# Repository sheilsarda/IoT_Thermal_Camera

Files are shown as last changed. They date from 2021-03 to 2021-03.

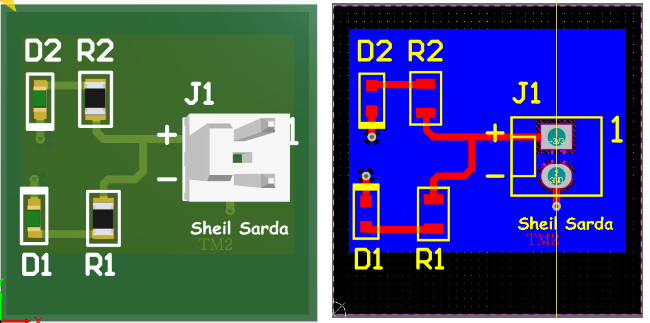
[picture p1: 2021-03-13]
Lab4/ESE516_SheilSarda_A4.png

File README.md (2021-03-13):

# Radiance-T 

IOT Device for Non Contact Temperature Measurement and Thermal Image Mapping 

## Inspiration
"**Industry 4.0** fosters what has been called a "smart factory". Within modular structured smart factories, cyber-physical systems monitor physical processes and make decentralized decisions. Industrial Internet of Things (IIoT) systems enable the connectivity of numerous heterogeneous devices and other assets into one system to derive more intelligent actions from data. The application of the IIoT in industrial production systems is known as Industry 4.0".(_[Wikipedia]_ [ABB_D]_)

Industrial automation companies including ABB, Bosch, BMW and Audi envision that in these smart factories of the future people will control the operations and make decisions based on measurement data from the factory's equipment, as well as information regarding the availability of raw materials and the price of energy. This will improve productivity, in more environmentally friendly manner and reduce costs. (_[ABB]_).

Our product, **Radiance-T** will give manufacturers the ability to transition personnel to more value-added activities, providing the foundation to extend and expand product and service offerings. As they look to expand globally, our automated temperature and thermal image monitoring solution will maintain process consistency across locations. The information will be delivered to experts who are far away from the facility itself, for example in applications for the oil and gas industry or for offshore wind power plants. The product can pre-emptively detect and analyze faults and send reports to operation and production planning systems.

## What it does
Our device provides clients with the ability to remotely access data from **Radiance**'s on-board thermographic camera and thermopile sensors to enforce quality control standards of temperature-sensitive goods such as perishables or heat-sensitive chemicals during processing or manufacturing. It enables clients to monitor and perform operations effectively on assembly and manufacturing lines. It provides the visual sight on location where human inspection or visual camera monitoring are difficult.

**Radiance**'s sensors are mounted on a 180-degree swivel platform powered by a remotely controlled servo motor, allowing the client to get temperature readings with a 235-degree field of view. All the logged data is easy accessible to clients via our cloud dashboard.

Clients can also update **Radiance**'s firmware to take advantage of the latest features using the Over The Air Firmware Update capabilities accessible through our cloud application interface/dashboard. 
Increasing automation improves the quality of the entire value chain. The person can use information to program and control operations and make decisions to optimize the quality, safety, efficiency and environmental aspects of production. 

**Application Features** </br>

## How we built it
1. Product design phase with feature and sensor selection.
2. Designing electrical schematics using Altium Designer to enable PCB design.
3. Designing PCB, routing components, satisfying manufacturers Design Rule Checks.
5. Exporting PCB design, submitting it to manufacturer and resolving any last-minute issues.
4. Developing firmware for the PCB, including developing a CLI, Bootloader, and OTAFU functionality using the Atmel Studio IDE and ASF libraries for the SAMD21 MCU.
6. Connecting the hardware to Node-Red using the MQTT broker.
7. Designing UI Interface for **Radiance** using Node-Red IDE with simulation functionality.
8. Perform board bring-up on our manufactured PCBs, and integrate sensors using I2C, Serial and ADC interfaces.

## Challenges we ran into
**Firmware Integration.** Following the checkpoint structure of the course, we developed all the core firmware functionality such as CLI, boot loader, OTAFU and each sensor's interface in independent projects. In the last few weeks of the course when we tried to merge all the software projects to create a singular 2000+ line project, we ran into a lot of conflicts. Examples were using different timers, sensor modules using the same SERCOM pins, or condensing or trying to compress a polling-based while(true) loop using interrupt driven programming. 

**PCB Design.** Our primary challenge in the second stage of our project was narrowing down the functionality and complexity of our board to fit under the $30 / board budget. Significant challenges we faced when tasked with designing the schematics and the board for our PCB, component selection based on size, availability and cost was major challenge. Moreover, complying with PCB manufacture's requirement was most important thing in this phase. 

**PCB Bring-up.**  Testing signal connectivity and voltage levels and making sure power blocks works as we designed them for.

**Sensor Integration** - Interfacing two different I2C sensors on the same I2C line with master processor and calibration of complex temperature sensor on the board.   

**Product Management**- Cost and timeline were major challenges in the development life cycle 

## Accomplishments that we're proud of
+  Build a working prototype for Radiance -T which can be tested with conditions
+  Designed a dashboard and analytics engine which works on cloud computing 
+  IOT practicum and hands on experience on industry standard  product development  
+  Successfully completing a IOT Edge Computing course at Penn

## What we learned
1. Building an IOT device from the ground up. 
2. The building blocks and technical requirements for developing a complete and generic IOT product
3. Circuit Design, PCB design and Firmware development using industry standard software and tools. 
4. Sensor Integration, Cloud connections, Wireless Communication and Power Management techniques
5. Processor, component and material selection and development timeline 
6. IOT design thinking, different phases and challenges in developing a product 

## What's next for Radiance
We are envisioning of building a minimal viable product and testing it on sight with more powerful sensors and analytics engine. We are planning to create a network of Radiance devices and automate the processes for smart factory. While creating Radiance's MVP, we are expanding the application of device in consumer and retail supply chain sector.  Data measurement and predictability will increase the operational reliability, uniformity, cost-effectiveness and safety all while making it easier to control remote locations. 

[Wikipedia]: https://en.wikipedia.org/wiki/Industry_4.0
[ABB]: https://new.abb.com/docs/default-source/technology/a-new-age-of-industrial-production---iotsp.pdf
[ABB_D]: https://new.abb.com/news/detail/11242/digital-twin-a-key-software-component-of-industry-40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

## Course Wrap-up (from Prof. Garcia's email)

Hello Everyone:

Thank you very much for your time and energy in this semester's class. I wanted to send this email as a wrap up of the class, to indicate some tips and next steps that I hope can prove useful. As an additional note, I have attached the Microchip Crypto Primer slides that Dan presented to the class.

### What comes after Altium - Alternatives

In the class we learned about PCB Design using Altium Studio which fortunately Penn has licenses for. There are free alternatives in case you want to continue developing PCBs but do not have access to Altium. They are:

1. [Circuit Maker](https://circuitmaker.com/). This is the online-based free version of Altium. will have most of the utility seen in class.  It is cloud based, which means all the projects will live on the cloud. I have used it and I consider it pretty good.
1. [KiCad](http://kicad-pcb.org/). Open source software for PCB development. Very popular alternative to Altium, and Free! It is also cross platform.
1. [Autodesk Eagle](https://www.autodesk.com/products/eagle/overview). I have not used it since the days it was free. Now it is $15 a month.

### PCB Fabrication
This class used PCB:NG for mixed results. I wanted to share some of my favorite PCB manufacturers with you to keep in mind if you want to do future PCB work.

1. [PCBWAY](https://www.pcbway.com/). Very good PCB fab house, based in China. You can quote the cost on the PCB and assembly online, and their process is very good. You can tell them (for assembly) to buy the components themselves, or send it to them directly from Digikey. I fully recommend them!
1. [Sierra Circuits](https://www.protoexpress.com/). Very good PCB fab house in the States (California). Really good turnaround - I would consider them if you are doing something for work or school - they are not in the price range for hobbyists! Their main advantage lies in that they do a very thorough analisys of your design, and they are very good at "catching" manufacturability issues and letting you know so they can be fixed.

### Interesting Microcontroller Recommendations

There are multiple interesting microcontrollers out there, each with their own advantages. i wanted to share some in case you would like to know more about them. The following options have very inexpensive dev kits you can buy on Amazon or Digikey.

1. ST: I really like ST and use them extensively. They have a supporting software, called CubeMX, which really helps with the phase of HW and FW design (very similar to Atmel Start). Give them a try!  https://www.st.com/content/st_com/en/support/learning/stm32-education.html
1. Rigado: If you need Bluetooth, I heavily recommend a micro from Nordic! Nordic make really good MCUs with built in Bluetooth, but they are very small and sometimes their size alone can drive the cost of the PCB manufacturing (smaller vias and traces equals a more expensive board!). This is sometimes dealt with with the use of modules. Rigado makes modules based on the Nordic chips that take care of complicated electronics needed to run the Nordic chip, and give you a nice module (A la SAMW25). They use a really good (free) development studio called Segger Embedded Studio (free for using the Nordic chips). Give them a try!  https://www.rigado.com/products/wireless-modules/

### Connectors

There exists a ton of connectors, and sometimes you may have seen a connector but have no idea what the name is to find them online! It happens to me a lot.

For this, I recommend the Connector page of Digikey (accesible from the front splash page - on the left, click on "connectors"). Or see this link: https://www.digikey.com/en/resources/connectors/index

You can then go through the connector selection with representative images of the connectors on each category.

### How useful is to know how to make PCBs? And how useful is to do personal projects as an Engineer?

I hope this class gave you the resources you need to bring any electrical project to manufacturing, be it a class project, an academia project, or an industry project.

As a finishing point I wanted to explain how important it is to do personal projects that you can showcase as a portafolio. Projects can be a great way to find new laboral opportunities and to showcase your skills and stand out.

As an example, I wanted to share the work of a friend and colleague. His name is Samson March, and he had been working as a pet project on making his own smart watch. I can attest he worked on it for a really long time. He recently published his project as a Open Source Project, and the project gained so much traction online that he started receiving job opportunities from very interesting companies. You can see the project [here](https://www.theverge.com/circuitbreaker/2019/5/5/18528008/smartwatch-build-your-own-diy-wearable).

I mention this example as a way to motivate you to do your own projects, which I hope this class helped on how to do. Also, on the importance of documentation of said projects! I would recommend, as you do your future school projects or personal projects, to document them AND to take nice pictures! I recommend lightboxes available on Amazon if you want to take nice pictures (Price around 10-50 dollars).

### Keep in Touch

If you want to keep in touch with me, my email is:

- `egarcia@bresslergroup.com`
- `edgarc@seas.upenn.edu`
- LinkedIn: `www.linkedin.com/in/EduardoEEGarcia`

Thank you everyone again for a great semester

Thanks!

-Eduardo

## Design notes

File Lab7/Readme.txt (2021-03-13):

README:
In order to check OTAFU via our dashboard, you can find the correct version numbers and CRC32 values by visiting
https://www.seas.upenn.edu/~sheils/metadata.txt

Line 1 of the metadata file is the version number, line 2 is the CRC32.
You will need to input these values to the Security Tab of our dashboard in order to successfuly update the Application Code.

The ApplicationCode.bin file being downloaded by OTAFU is hosted at 
https://www.seas.upenn.edu/~sheils/ApplicationCode.bin

You can find our dashboard at
https://radiancet.mybluemix.net/ui/#!/0

Since we did not make any modifications to our bootloader from A6, we did not need to add the bootloader project to our Atmel Studio solution for A7. The packaged code submitted in this directory is our application code for A7 only.

Our A6 Bootloader code can be found in the A6 folder in our project directory.

For the purposes of adding modules that we will be using in our final project, we added the Sercom I2C slave and master drivers, in addition to the Sercom SPI serial driver.

For testing purposes, we have also attateched the pre-OTAFU bin files and CRC files, which our bootloader expects to be loaded on the SD Card prior to boot. The post-OTAFU equivalents are hosted on the Penn server.

End to end OTAFU Demo: https://www.youtube.com/watch?v=R9AgcVQNr38

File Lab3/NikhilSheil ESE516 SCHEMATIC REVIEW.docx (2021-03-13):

# ESE516 SCHEMATIC REVIEW (A3)

Review Team | NikhilSheil
Teammember A | Nikhil Jamdade
Teammember B | Sheil Sarda
Reviewer | Eduardo Garcia
Date | Feb 24 2019
Project File | ESE516_ExampleBaseProject_V2.PrjPcb (Feb 22, 2019)

Main Schematic

• Good idea on connecting the BQ Enable and SYSOFF to the MCU Pins. However, for safety I recommend adding pulldowns or pullups depending on the default setting you want. I recommend putting a 10k pulldown on each of lines (BQ_SYSOFF, BQ_EN1, BQ_EN2). I also recommend removing the inline jumpers – they are now needed in this case.

- VUSB are not connected – was your intention to use an external supply just in case? In general, use Power ports for power nets.

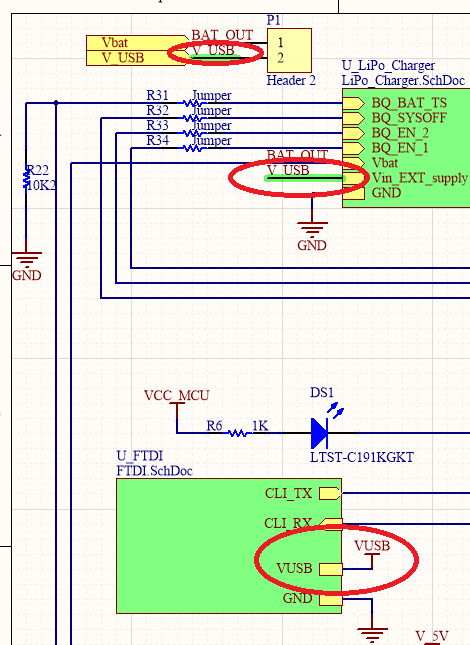
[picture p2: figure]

- For the battery connector, please add its own connector with VBAT and GND.
- Critical: The buzzer needs a square wave, make sure the pin you chose can do a PWM output. Also, you need to add a BJT to handle the current – see the datasheet. The MCU cannot provide the current needed directly from the pins.

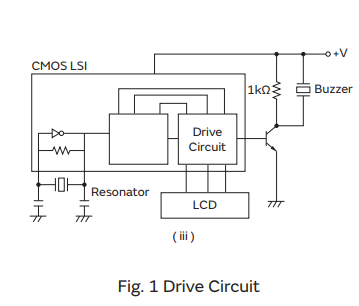
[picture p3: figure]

- Resistor R21 is not doing anything

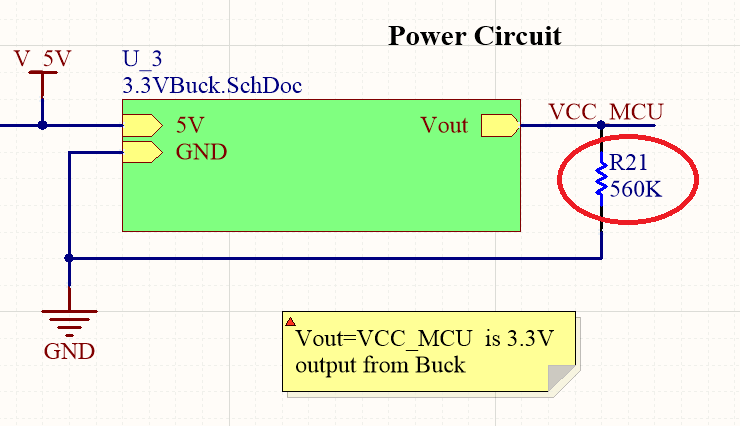
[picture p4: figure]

- Please add ERC to pins not used.
- Add testpoints for I2C lines and INT lines as well as servo PWM and feedback.

LiPo Fuel Gauge Schematic

- Please add a ground port to make the schematic clearer.
- Please change the designator of the device from Fuel Gauge to U? where the ? is an unique number in your design.
- This IC has no associated footprint. Please make and add the respective footprint.
- Please add the MPN. I cannot review without it.
- Critical: Device is wrong! Pin numbers are incorrect. Please double check with datasheet and update the device to have the correct pinout.
- Critical: The schematic is wrong! Please follow section 10.2 of the datasheet: http://www.ti.com/lit/ds/symlink/bq27441-g1.pdf

5V BOOST

- Critical - TPS61230DRCR needs a feedback resistor divider – please see the datasheet. HOWEVER, if you meant to use the TPS61232DRC, which is the fixed 5V output, then you can leave FB connected, but you have to change the component to be TPS61232DRC.

3V3 BUCK

- Component has some issues:
  - Critical: Component is wrong! Pins are incorrect. Please redo part and check datasheet Section 5: http://www.ti.com/lit/ds/symlink/tlv62568a.pdf
  - Critical: Feedback resistors are missing. Please check datasheet Section 5: http://www.ti.com/lit/ds/symlink/tlv62568a.pdf

IR Thermometer

- Component has no associated footprint

• Please change the designator of the device to U? where the ? is an unique number in your design.

- Add MPN to device. I am assuming it is the MLX90614ESF-BAA-000-TU

Servo Motor Schematic

- Component has no footprint. Please associate a footprint.

Thermal Camera Schematic

- Component is missing pin names and footprint. Fortunately the AMG8833 component is available on Altium Vault – please consider using that one, or fix your existing component.
- Please check the schematic with https://learn.adafruit.com/assets/43011 . R36 is doing nothing – if you want to have the option of selecting high or low, put a jumper between the AD_Select pin and ground.

MCU Schematic

pin checkout

SERCOM 1 is for SPI for WINC

SERCOM 4 is for UART CLI

SERCOM 3 for IR I2C – PA17 SCL, PA22 SDA

SERCOM 0 for Thermal and fuel gauge – PA08 SDA, PA09 SCL

ADC A0 PA02 for analog input

PA24: TC5/WO[0] OR TCC1/ WO[2]

- Critical: PA09 is connected as if it were SDA but Atmel Start tells me it is SCL. SAME FOR PA08. Please double check and fix!
- Critical: The analog of the SAMD21 must be from 0V to VCCA/2 (which is 1.65V). You will need to use a voltage divider to scale the ADC input from the servo. Also, the net label should read SERVO_ADC, not SERVO_DAC
- I recommend adding a button and an extra LED for debugging purposes or for system on/off.
- Please connect pin 10 to GND.

General Comments

Please review ALL the components that were made by hand. They have missing footprints and the symbols are wrong. Refer to the tutorial we did in class for steps on how to do this.

Add an external connector for the battery only (positive and negative terminal).

I recommend to implement the fixes and pair review the schematic.

Grade:

Component: -40 points: There are multiple component issues that if they made it to manufacturing would make the board not work. Please pair review the components you make with the datasheet, as it is easy to miss mistakes. Also, make sure footprints are associated with component.

Schematic Errors: -25 points: There are some errors that could have been caught if you double check the layout with the datasheet (which is something I recommend you to always do). It is easy to make mistakes while wiring schematics.

Grade: 235/300

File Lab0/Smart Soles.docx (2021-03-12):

# Smart Soles

# Navigation for the Differently Abled

I wish to build an IoT connected insoles to assist the differently-abled population (sight or sound impaired, for instance) safely navigate to their destination using directions provided in the form of haptic feedback from the shoes.

My idea of this device would consist of the following:

- 4 x Vibrating motor (or any low current motor) – two in each shoe
- 2 x Motor Drivers – each can drive up to 3 motors
- Wi-Fi chip to fetch instructions from a server – these instructions will trigger the motors when user needs to change their trajectory
- GNSS / GPS chip to get position of the user – this is a necessary input in determining when to activate the motors

Considerations: If GPS turns out to be too expensive, can be figure out a lower cost alternative to localize the user using Wi-Fi perhaps? The tradeoff would be cost vs. accuracy.

Simple System Diagram

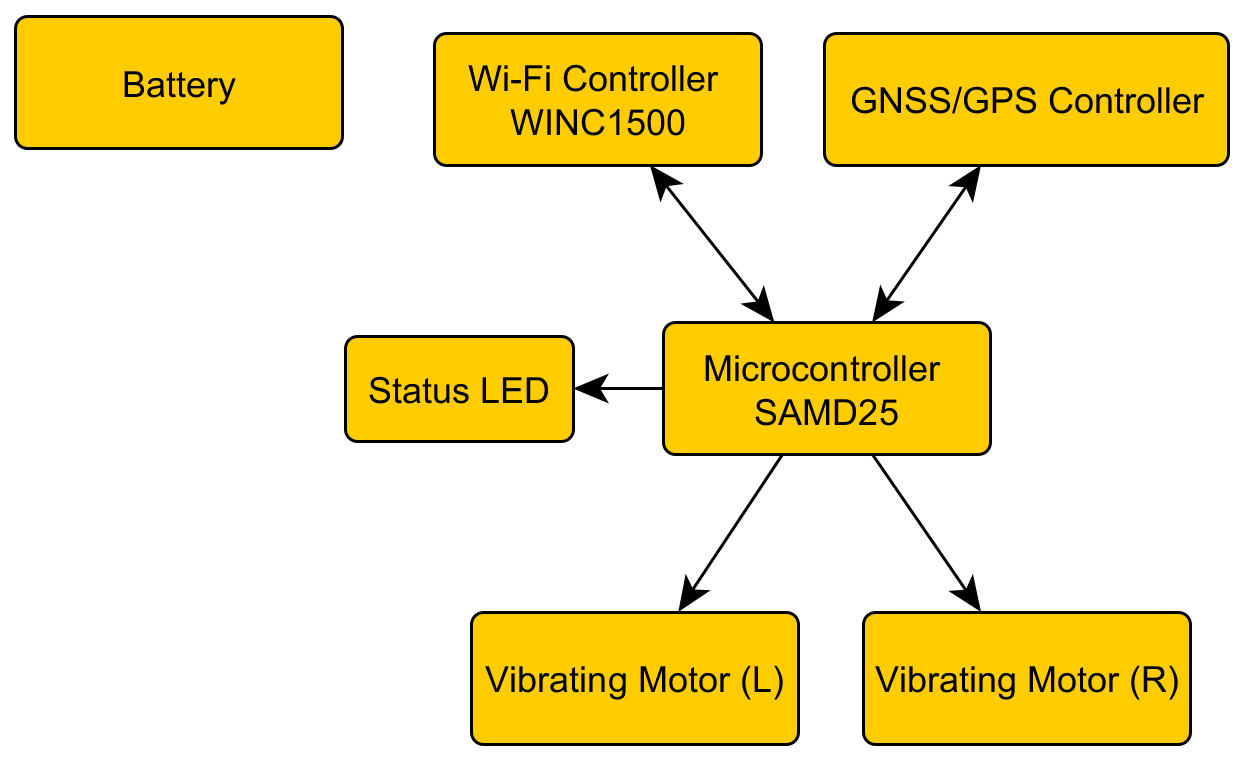
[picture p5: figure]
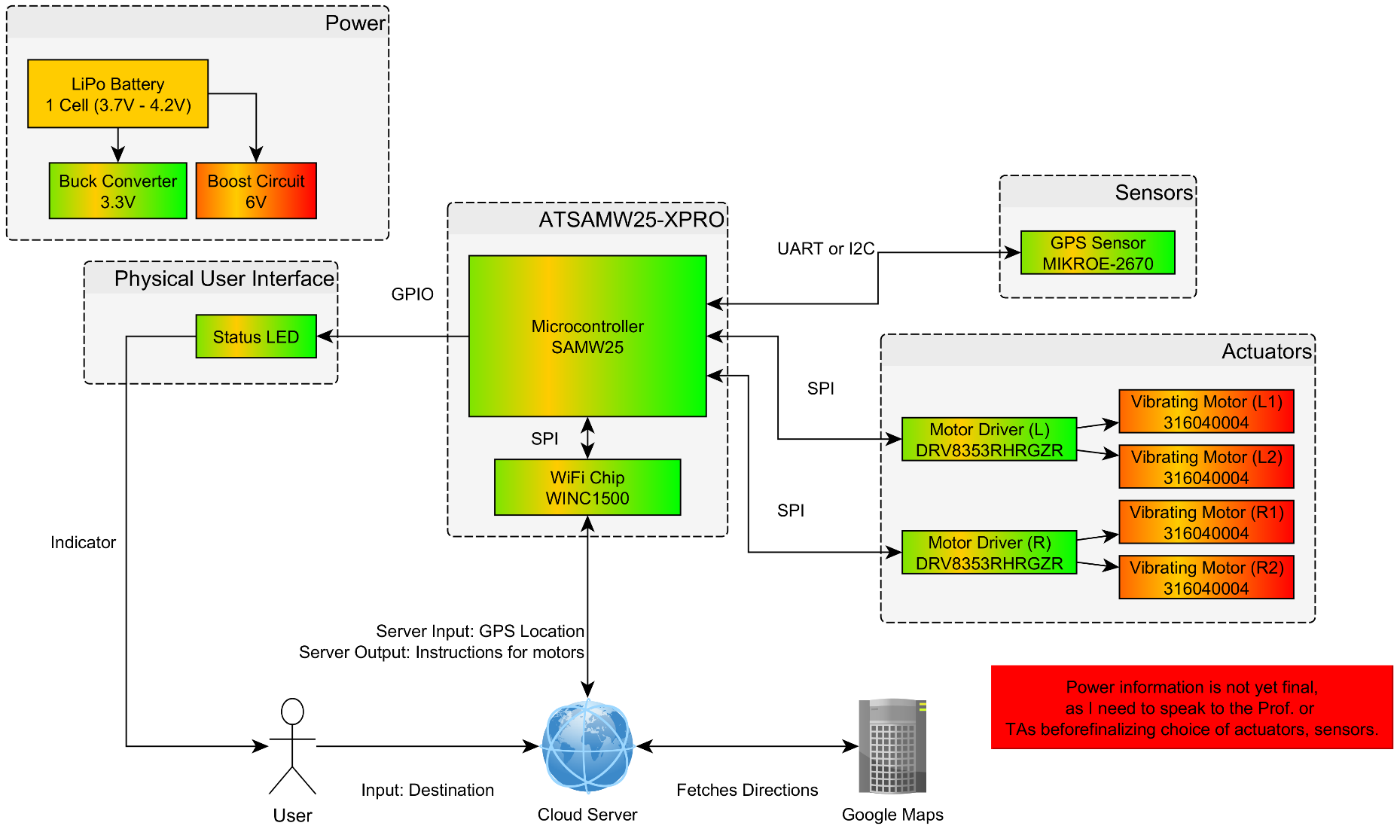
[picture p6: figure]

Detailed System Diagram

4.) Detailed System Diagram [50/50]

COMMENTS:

1.) Good description of the problem and good analysis of the technical challenges. Indeed! Location of a person on a building is a very hard problem - GPS can have issues inside buildings and usually has a tolerance that is ok to drive cars with, but it is too big for people walking inside buildings. There are some radios that try to do this location, but it is a hard problem. I worry that the product, as is ideally thought of, might be too hard to implement for this class. Let's talk after class this monday!

3.) The motor drivers are SPI drivers for thee phase BLCD motors. That is some serious motor controller! The vibrating motors you selected do not need this very complicated motor driver. For these motors, you can use either a simple BJT (turn on/off) or even more interesting, a haptic driver. Haptic driver are specialized drivers that allow you to do cool stuff with haptics. Check for example which is a better fir for your product.

https://www.adafruit.com/product/2305

Sheil Sarda ESE516 Project A0 Prof. Garcia

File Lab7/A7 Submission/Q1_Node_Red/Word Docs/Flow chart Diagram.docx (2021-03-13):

Radiance T : Flow Diagram from Device to MQTT to Cloud

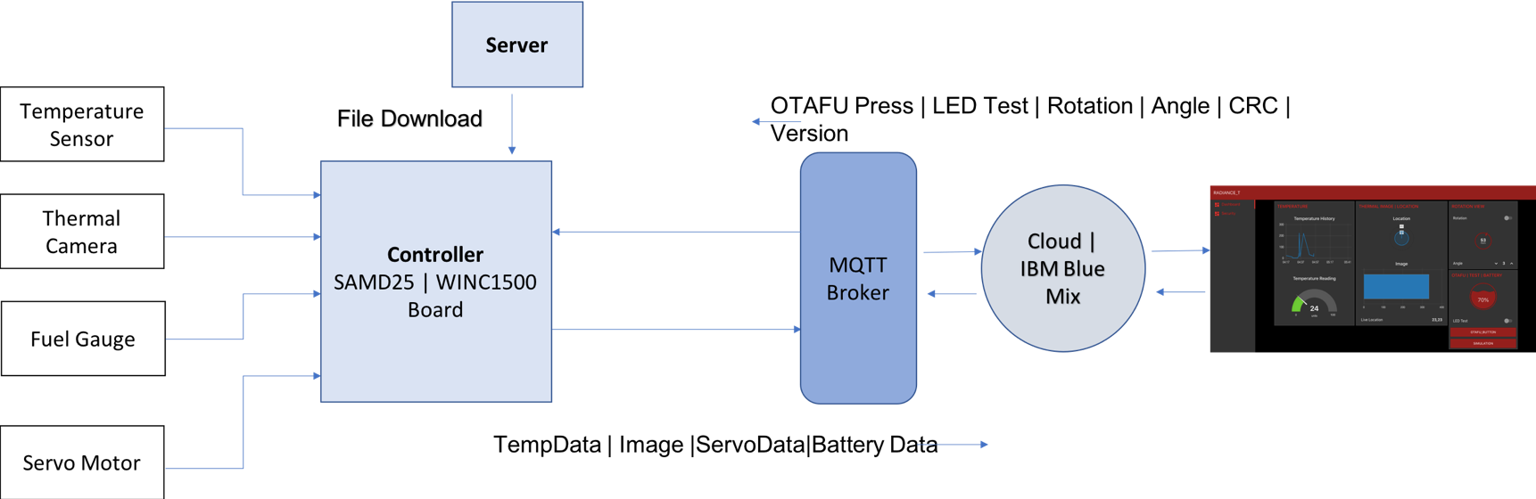
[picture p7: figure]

Message Transmission

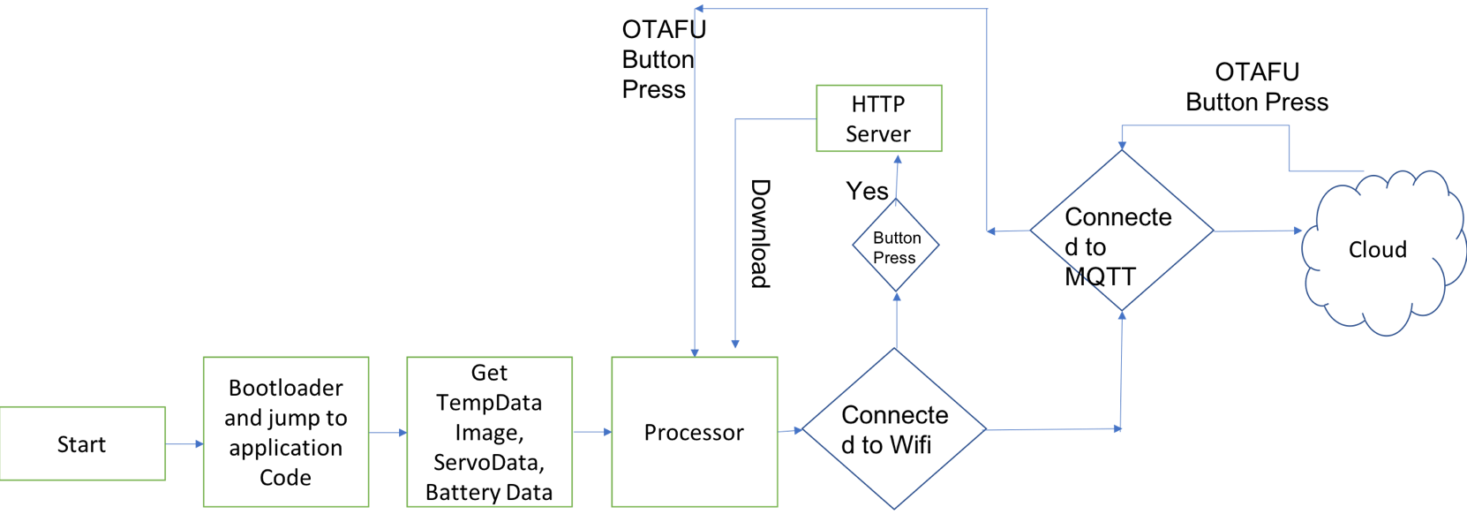
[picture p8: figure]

OTAFU Operation

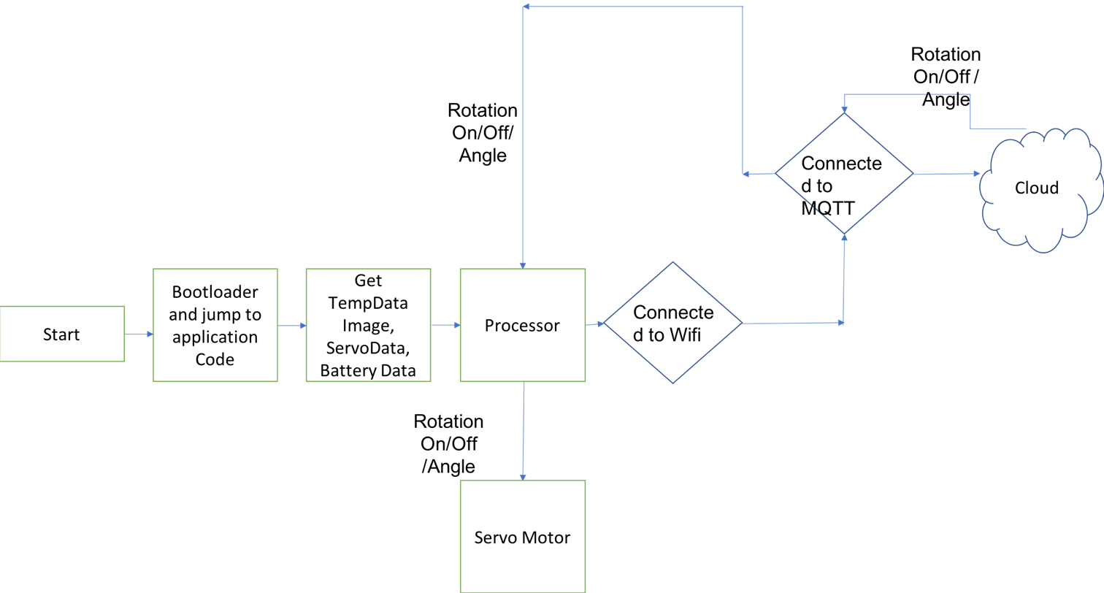
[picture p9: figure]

Servo Operation

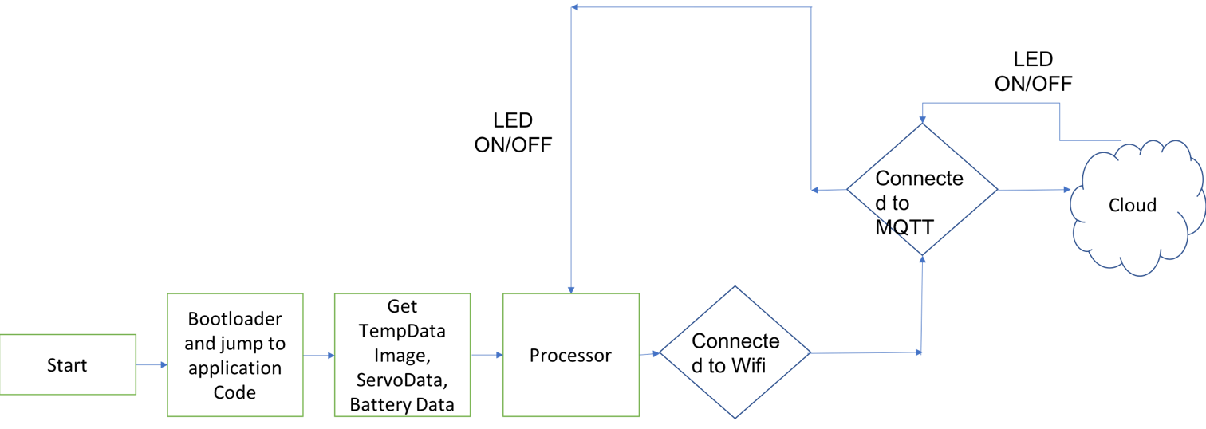
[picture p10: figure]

LED

Operation

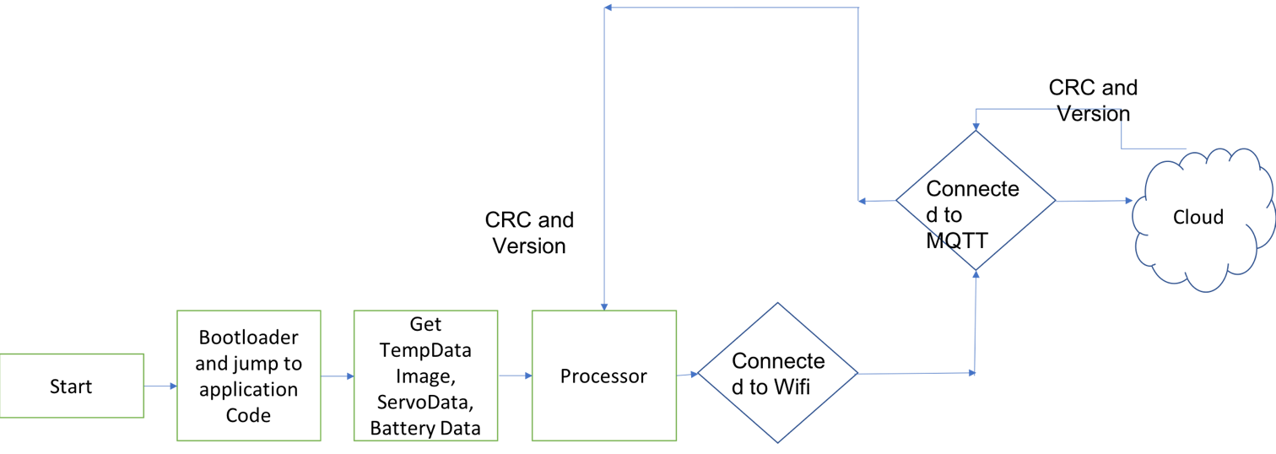
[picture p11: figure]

MetaData Trasfer

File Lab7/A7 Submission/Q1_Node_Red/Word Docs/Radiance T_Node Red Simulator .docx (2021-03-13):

Link to Node Red Radiance-T Dashboard

https://radiancet.mybluemix.net/ui/#!/0

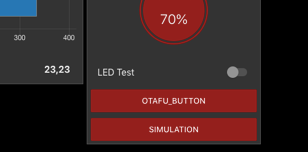
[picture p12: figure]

Device Simulator Node Red Diagram

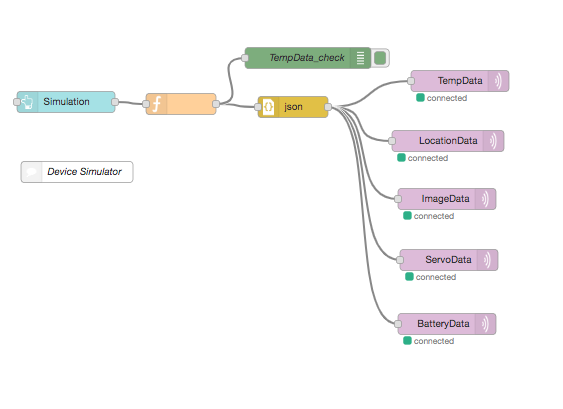
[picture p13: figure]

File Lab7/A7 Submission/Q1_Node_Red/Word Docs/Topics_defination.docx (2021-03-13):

ESE 516: Assignment A7

Creating the Node-Red dashboard for Radiance-T project

- Messages from Device ---- MQTT---- IBM Bluemix

Topic 1 : LocationData

Type : Number

JSON Structure:

var long1;

var lat1;

msg = {

payload: JSON.stringify(

{

d:{

"loc" :

{

"long" : long

"lat" : la1t },

}

} )

};

return msg;

Information – Sends the location coordinates or device id to display on the

Board. The graph on dashboard shows the location map.

Topic 2 : TempData

Type : Number

JSON Structure

Var temp1

msg = {

payload: JSON.stringify(

{

d:{

“temp” :temp1

}, } } )};

return msg;

Information – Sends the temperature data from IR temperature sensor on the device to

display and analyze temperature on cloud. The graph on dashboard shows the temperature history over time.

Topic 3 : ImageData

Type : Number Array

JSON Structure

Var image1=[1,2,3,4,5,6,7,8]

msg = {

payload: JSON.stringify(

{

d: {

“img” :{one: image1[0],two:image1[1], three:image1[3], four:image1[4]

}, } } )};

return msg;

Information – Sends the raw thermal image data group of bits/pixel from thermal camera on the device to display and analyze it on cloud.

Topic 4 : ServoData

Type : Number

JSON Structure

Var servo1

msg = {

payload: JSON.stringify(

{

d: {

“servo”:servo1

}, } } )};

return msg;

Information – Sends the stepper motor feedback/angle from device location to cloud. It is used to check the direction on sensor on device. It also gives rotation and movement of motor.

Topic 5 : BatteryData

Type : Number

JSON Structure

Var batt1

msg = {

payload: JSON.stringify(

{

d: {

“batt”:batt1

}, } } )};

return msg;

Information – Sends the reading of batter power from fuel gauge on device to cloud. It is used to show the amount of power left.

- Messages from IBM Bluemix------- MQTT------ Device

Topic 1: RotationData (ANGLE_TOPIC)

Type : Number

JSON Structure

int data

msg = {

payload: JSON.stringify(

{

d: {

data:data

}, } } )};

return msg;

Information – Sends the specific angle from cloud to rotate the motor on device side

Information – Sends the specific angle from cloud to rotate the motor on device side

Topic 2: StopData (STOP TOPIC)

Type : Boolean

JSON Structure

boolean data

msg = {

payload: JSON.stringify(

{

d: {

“datat”:data

}, } } )};

return msg;

Information – Sets continuous rotation of motor on or off- Rotation enable or disable

Topic 4: LedData (LED_TOPIC)

Type : Boolean

JSON Structure

boolean data

msg = {

payload: JSON.stringify(

{

d: {

“data”:data

}, } } )};

return msg;

Information – Sends signal from cloud to device to test the led on device

Topic 5: FW_Data (FW_TOPIC)

Type : Boolean

JSON Structure

Boolean data

msg = {

payload: JSON.stringify(

{

d: {

“data”:data

}, } } )};

return msg;

Information – Triggers OTAFU from cloud on device to download new firmware from server.

Topic 6: CRCData (CRC_TOPIC)

Type : String

JSON Structure

Char * data

msg = {

payload: JSON.stringify(

{

d: {

“data”:data

}, } } )};

return msg;

Information – Sends CRC string for OTAFU operation to write on SD card before download and update

Topic 6: VerData (VER_TOPIC)

Type : number

JSON Structure

Int * data

msg = {

payload: JSON.stringify(

{

d: {

“data”:data

}, } } )};

return msg;

Information – Sends version number for OTAFU operation to write on SD card before download and update

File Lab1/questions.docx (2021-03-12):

1.) What does “InitializeSerialConsole()” do? In said function, what is “cbufRx” and “cbufTx”?

It initializes the circular buffers handlers cbufRx, cbufTx as 8-bit integer buffers that use the underlying arrays rxCharacterBuffer and txCharacterBuffer while using 2 pointers to access different parts of the array. These circular buffers can hold at most 256 elements each.

2.) How are “cbufRx” and “cbufTx” initialized? Where is the library that defines them (please tell the *C file they come from).

They are initialized in the InitializeSerialConsole function inside SerialConsole.c

The function used to initialize them is called circular_buf_init, which is located in circular_buffer.c

In the initialization, we malloc and return a pointer to the space for the circular_buf_t struct, which contains the local variables necessary to implement the interface of the circular buffer using an underlying char array.

3.) Where are the character arrays where the RX and TX characters are being stored on at the end?

SerialConsole.c contains rxCharacterBuffer and txCharacterBuffer, which is where the RX and TX characters are being stored via the Circular Buffer interface

4.) Please draw a diagram that explain the program flow for UART reception – starting at the user typing a character and ending on how that characters ends up in the circular buffer “cbufRx”. Please make reference to specific functions in the starter code.

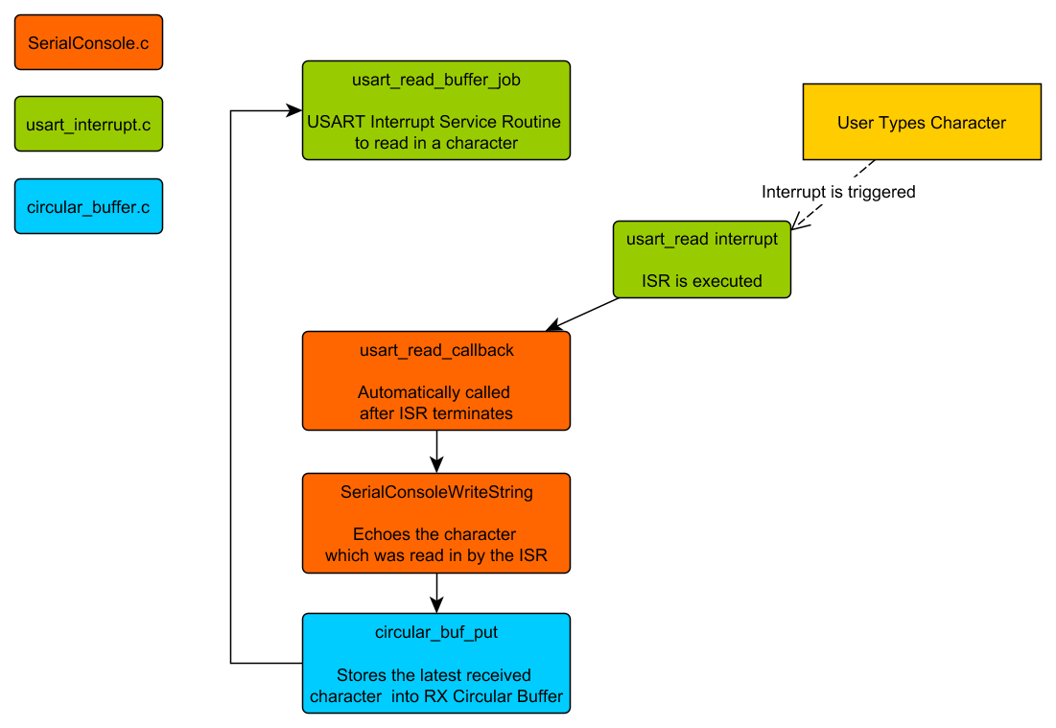
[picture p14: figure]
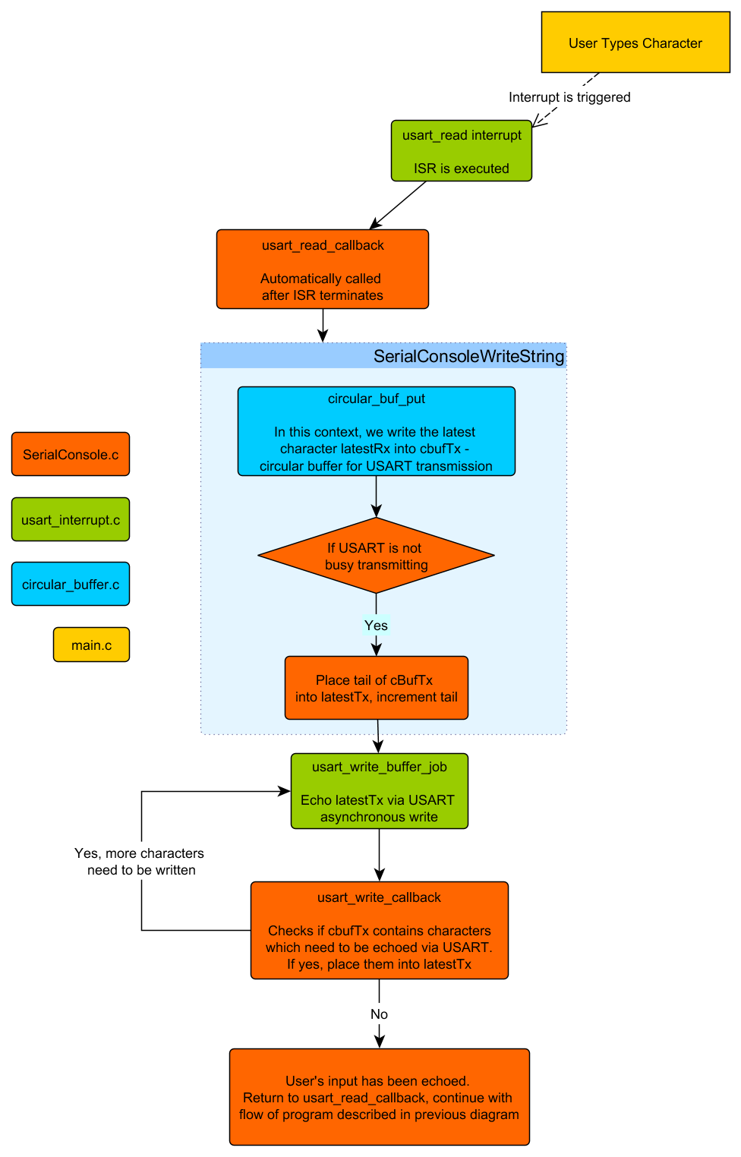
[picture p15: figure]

5.) Please draw a diagram that explain the program flow for the UART transmission – Starting from a string added by the program to the circular buffer “cbufTx” and ending on characters being shown on the screen of a PC (On Teraterm, for example). Please make reference to specific functions in the starter code.

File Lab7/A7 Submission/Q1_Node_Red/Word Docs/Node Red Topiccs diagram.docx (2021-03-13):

Link to Node Red Radiance-T Dashboard

https://radiancet.mybluemix.net/ui/#!/0

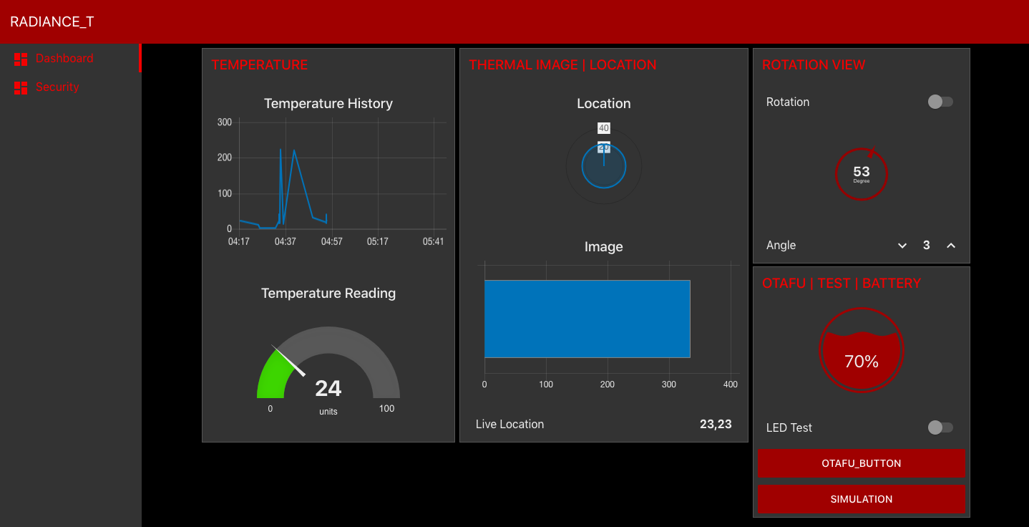
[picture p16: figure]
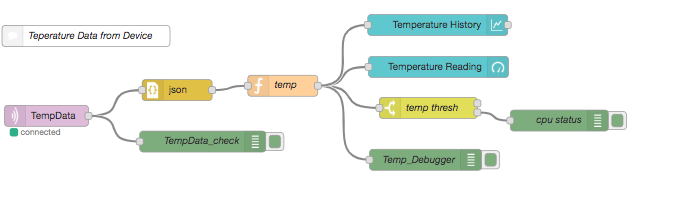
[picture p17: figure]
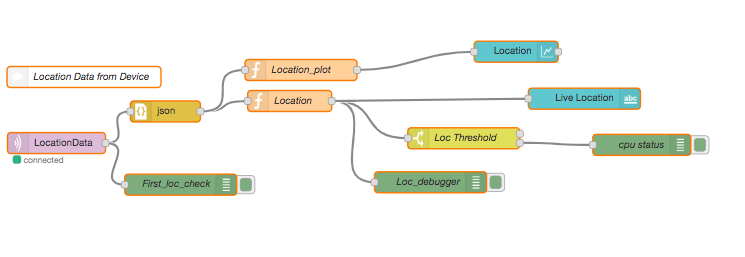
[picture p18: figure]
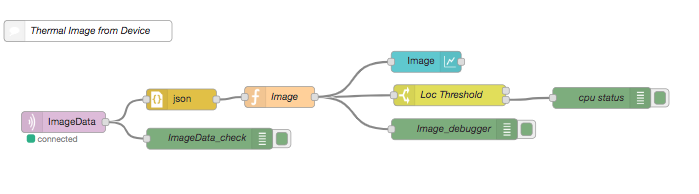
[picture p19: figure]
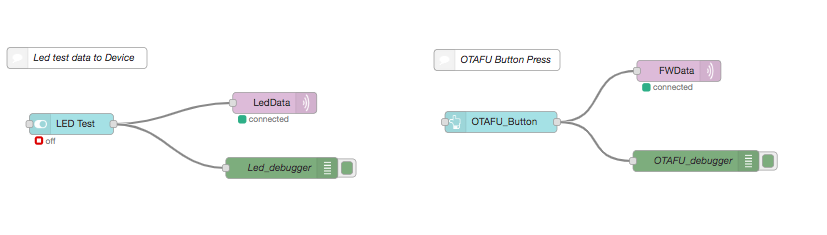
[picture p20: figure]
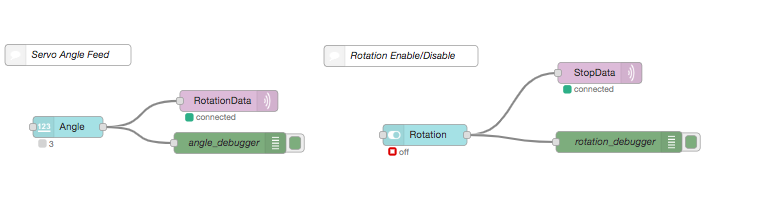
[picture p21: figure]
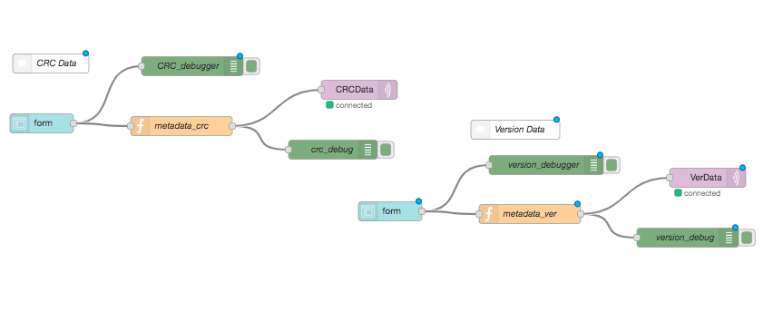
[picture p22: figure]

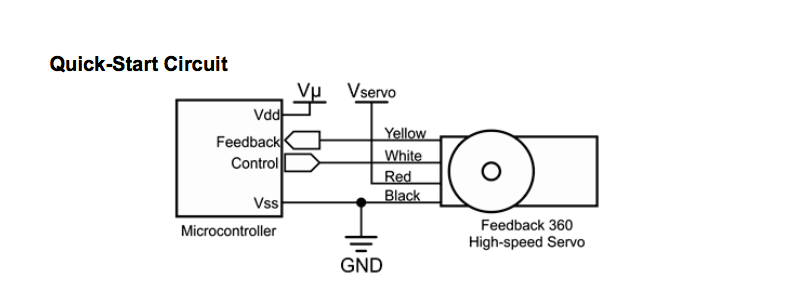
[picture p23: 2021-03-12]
imgs/Servo Motor.png

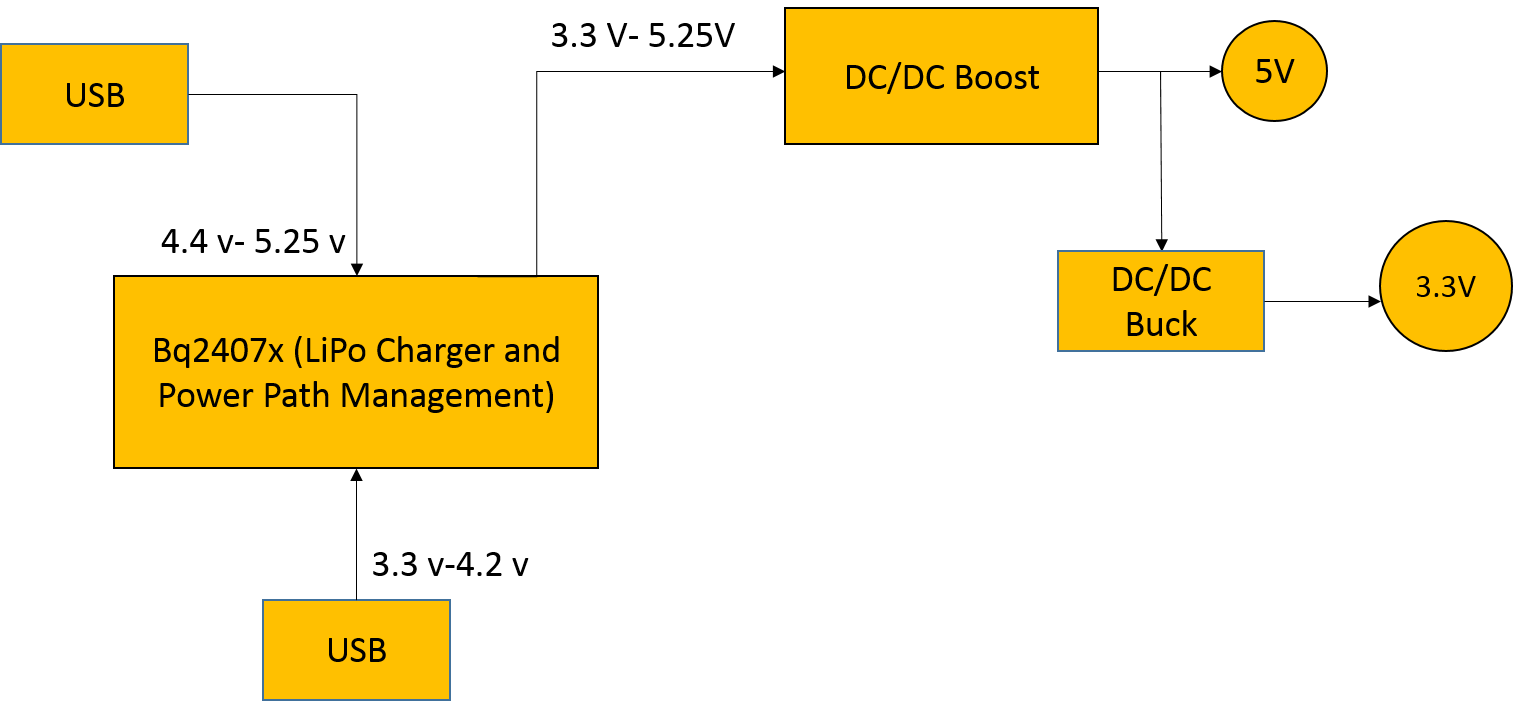
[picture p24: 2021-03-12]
imgs/High Level Circuit Diagram.png

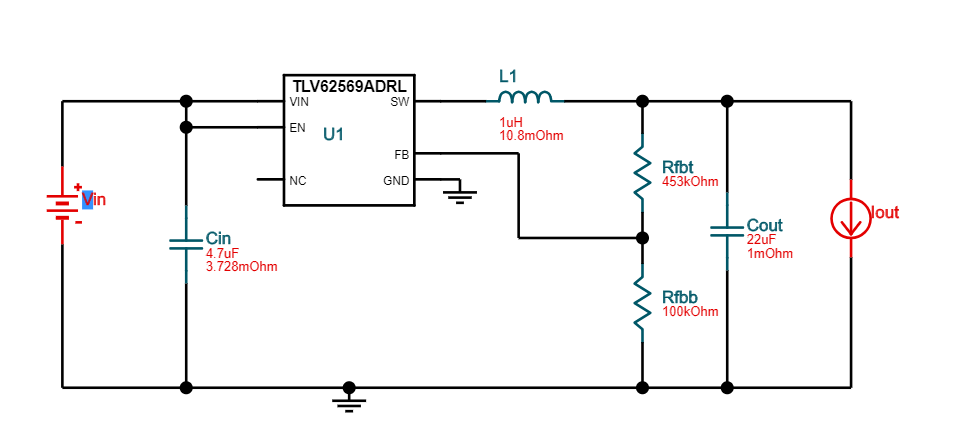
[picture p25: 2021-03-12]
imgs/3.3V Buck Converter.PNG

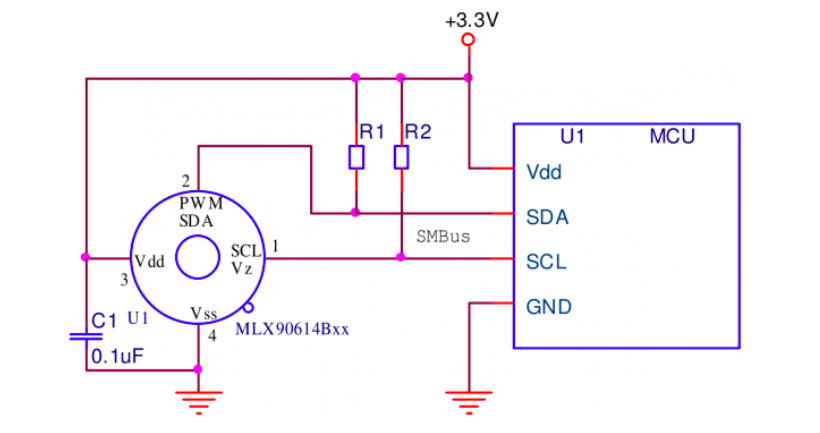
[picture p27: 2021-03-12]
imgs/IR Circuit.png

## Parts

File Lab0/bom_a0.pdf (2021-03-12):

Component | MPN | Manufacturer | PN | Source | Min. Volt. | Max. Volt. | Interface to MCU | Qty | Cost QTY1 | Cost QTY1K | Comments | Link
Dev Board | ATSAMW25-XPRO | Microchip | ATSAMW25-XPRO | digikey | 4.3V | 5.5V | | 1 | 41.04 | 40 | ESE516 MCU + SoC Wifi
GPS Sensor | MIKROE-2670 | MikroElektronika | 1471-1837-ND | digikey | 3.3V | 5V | IO Pins | 1 | 41.82 | 41 | Need to get Prof.'s feedback on what the best way to get location (coordinates) of the user would be
Vibrating Motor | 316040004 | Seeed Technology | 1597-1245-ND | digikey | DC 2.5V | DC 3.5V | IO Pins | 4 | 1.44 | 1.2 | Need to do additional research to find out what the optimal strength of the motor should be. I am counting in 4, since I plan on using 2 motors in each of the 2 soles. | Here (https://www.digikey.com/product-detail/en/seeed-technology-co-ltd/316040004/1597-1245-ND/5487673)
Motor Driver | DRV8353RHRGZR | TI | 595-DRV8353RHRGZR | mouser | 9V | 75V | IO Pins | 2 | 6.11 | 3.07 | Provides 350mA current output and can drive 3 motors, which should be more than enough for the vibrating motors. There is also an alternative version available ($5.79), which does not provide the 3 voltage shunt amplifiers this model provides. | Here (https://www.mouser.com/new/Texas-Instruments/ti-drv835x-drivers/)
Total | 100.84 | 91.94

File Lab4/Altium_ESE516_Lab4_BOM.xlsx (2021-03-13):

Team TM2
Sheil Sarda
Nikhil Jamdade
Line # | Name | Description | Designator | Quantity | Manufacturer 1 | Manufacturer Part Number 1 | Manufacturer Lifecycle 1 | Supplier 1 | Supplier Part Number 1 | Supplier Unit Price 1 | Supplier Subtotal 1
 | Servo Motor |  |  | 0 | Adafruit Industries | 1404 | Volume Production | Digi-Key | 1528-1087-ND | 14 | 14
 | TPS61230DRCR | Boost Converter with 5 A Switch, 2.3 to 5.5 V Input Voltage, 2.5 to 5.5 V Output Voltage, -40 to 85 degC, 10-Pin SON (DRC), Green (RoHS & no Sb/Br), Tape and Reel | 1 | 1 | Texas Instruments | TPS61230DRCR | Volume Production | Digi-Key | 296-37761-6-ND | 2.54 | 2.54
 | PTS810 SJK 250 SMTR LFS | SWITCH TACTILE SPST-NO 0.05A 16V Tactile Switch SPST-NO Top Actuated Surface Mount | B1 | 1 | ITT C&K | PTS810SJK250SMTRLFS | Volume Production | Digi-Key | CKN10503CT-ND | 0.3 | 0.3
 |  |  | Buck Converter1 | 1 | Texas Instruments | TLV62569ADRLR | Unknown | Digi-Key | 296-51692-6-ND | 1.32 | 1.32
 | CAP 22uF 10V 0805(2012) | CAP 22uF 10V ±20% 0805 (2012 Metric) Thickness 1mm SMD | C1, C4 | 2 | KEMET | T529P226M010AAE200 | Volume Production | Digi-Key | 399-10534-6-ND | 1.35 | 2.7
 | CAP 4.7uF 16V 0805(2012) | CAP 4.7uF 16V ±10% 0805 (2012 Metric) Thickness 1.45mm SMD | C2, C8, C11, C17, C18 | 5 | KEMET | C0805C475K4PAC-TU | Volume Production | Digi-Key | 399-8101-6-ND | 0.28 | 1.4
 | CAP 10uF 16V 0805(2012) | CAP 10uF 16V ±10% 0805 (2012 Metric) Thickness 1.45mm SMD | C3, C21, C22, C23 | 4 | Kyocera AVX | 0805YD106KAT2A | Volume Production | Digi-Key | 478-5165-6-ND | 0.74 | 2.96
 | 08055C124KAT2A |  | C5 | 1 | Kyocera AVX | 08055C124KAT2A | Volume Production | Digi-Key | 478-1396-6-ND | 0.32 | 0.32
 | CAP 100nF 16V 0805(2012) | CAP 100nF 16V ±20% 0805 (2012 Metric) Thickness 1.45mm SMD | C6, C7, C9, C14, C15 | 5 | Kyocera AVX | 0805YC104KAT2A | Volume Production | Digi-Key | 478-7961-1-ND | 0.3 | 1.5
 | CAP 10nF 16V 0603(1608) | CAP 10nF 16V ±10% 0603 (1608 Metric) Thickness 1mm SMD | C10 | 1 | Yageo | CC0603KRX7R7BB103 | Volume Production | Digi-Key | 311-3369-6-ND | 0.1 | 0.1
 | CAP 47pF 16V 0805(2012) | CAP 47pF 16V ±2% 0805 (2012 Metric) Thickness 0.75mm SMD | C12, C13 | 2 | Kyocera AVX | 0805YA470JAT2A | Volume Production | Digi-Key | 478-11916-1-ND | 0.33 | 0.66
 | CAP 1uF 16V 0805(2012) | CAP 1uF 16V ±20% 0805 (2012 Metric) Thickness 1mm SMD | C16, C19 | 2 | KEMET | C0805C105M4RACTU | Volume Production | Digi-Key | 399-8009-6-ND | 0.33 | 0.66
 | GRM2165C2A471JA01D |  | C20 | 1 | Murata | GRM2165C2A471JA01D | Volume Production | Digi-Key | 490-1611-6-ND | 0.26 | 0.26
 | CAP 18pF 10V 0805(2012) | CAP 18pF 10V ±1% 0805 (2012 Metric) Thickness 0.75mm SMD | C24, C25 | 2 | Vishay Vitramon | VJ0805A180GXQCW1BC | Volume Production | Digi-Key | 720-1709-6-ND | 0.29 | 0.58
 | CAP 1uF 16V 0603(1608) | CAP 1uF 16V ±10% 0603 (1608 Metric) Thickness 1mm SMD | C26, C27, C28 | 3 | Kyocera AVX | 0603YC105KAT2A | Volume Production | Digi-Key | 478-5010-6-ND | 0.27 | 0.81
 | CAP 100nF 16V 0603(1608) | CAP 100nF 16V ±10% 0603 (1608 Metric) Thickness 1mm SMD | C29, C32 | 2 | Yageo | CC0603KRX7R7BB104 | Volume Production | Digi-Key | 311-1088-6-ND | 0.12 | 0.24
 | CAP 2.2uF 10V 0603(1608) | CAP 2.2uF 10V ±10% 0603 (1608 Metric) Thickness 1mm SMD | C30 | 1 | Yageo | CC0603KRX5R6BB225 | Volume Production | Digi-Key | 311-1451-6-ND | 0.23 | 0.23
 | CAP 10uF 10V 0603(1608) | CAP 10uF 10V ±10% 0603 (1608 Metric) Thickness 1mm SMD | C31 | 1 | TDK | C1608X5R1A106K080AC | Volume Production | Digi-Key | 445-7486-1-ND | 0.62 | 0.62
 | CAP 1uF 16V 0603(1608) | CAP 1uF 16V ±5% 0603 (1608 Metric) Thickness 1mm SMD | C33 | 1 | Kyocera AVX | 0603YC105JAT2A | Volume Production | Digi-Key | 478-10814-6-ND | 0.29 | 0.29
 | USBLC6-4SC6 | Very Low Capacitance ESD Protection, 3 pF, 4 Protection Lines, -40 to 125 degC, 6-Pin SOT23, RoHS, Tape and Reel | D1 | 1 | STMicroelectronics | USBLC6-4SC6 | Volume Production | Digi-Key | 497-4492-1-ND | 0.52 | 0.52
 | LTST-C170CKT | LED RED CLEAR 0805 SMD | D2 | 1 | Vishay Lite-On | LTST-C170CKT | Volume Production | Digi-Key | 160-1176-6-ND | 0.38 | 0.38
 | LTST-C170GKT | LED Uni-Color Green, 100 mW, 120 mA, -55 to 85 degC, 2-Pin SMD, RoHS, Tape and Reel | D3 | 1 | Vishay Lite-On | LTST-C170GKT | Volume Production | Digi-Key | 160-1179-6-ND | 0.33 | 0.33
 | LTST-C191KGKT | Chip LED, Green, 574 nm, 40 pF, -55 to 85 degC, 2-Pin SMD, RoHS, Tape and Reel | DS1, DS2, DS3, DS4 | 4 | Vishay Lite-On | LTST-C191KGKT | Volume Production | Digi-Key | 160-1446-1-ND | 0.29 | 1.16
 | BLM15AG100SN1D | Chip Ferrite Bead for General Use, 10 Ohm, 1000 mA, -55 to 125 degC, 1 x 0.5 x 0.55 mm SMD, Tape and Reel | FB1 | 1 | Murata | BLM15AG100SN1D | Volume Production | Digi-Key | 490-5176-6-ND | 0.1 | 0.1
 |  |  | Fuel Gauge1 | 1 | Texas Instruments | BQ27441DRZR-G1A | Volume Production | Digi-Key | 296-39941-1-ND | 2.62 | 2.62
 | IR Thermometer |  | IR | 1 | Melexis | MLX90614ESF-BAA-000-TU | Volume Production | Digi-Key | MLX90614ESF-BAA-000-TU-ND | 14.83 | 14.83
 | Micro-USB | CONN USB MICRO B RECPT SMT R/A | J1 | 1 | Amphenol FCI | 10118192-0001LF | Volume Production | Digi-Key | 609-4613-1-ND | 0.42 | 0.42
 | SDR0403-1R0ML | SDR0403 Series Power Inductor, 1 uF +/- 20 %, 0.033 Ohm, -40 to 125 degC, 2-Pin SMD, RoHS, Tape and Reel | L1 | 1 | Bourns | SDR0403-1R0ML | Volume Production | Digi-Key | SDR0403-1R0MLDKR-ND | 0.6 | 0.6
 | 74438323010 | Power Multilayer Inductor WE-MAPI, L=1.0µH | L2 | 1 | Wurth Electronics | 74438323010 | Volume Production | Digi-Key | 732-4843-1-ND | 1.13 | 1.13
 | 640456-4 | Male Header, Pitch 2.54 mm, 1 x 4 Position, Height 10.03 mm, Tail Length 3.56 mm, RoHS, Bulk | P1 | 1 | TE Connectivity | 640456-4 | Volume Production | Digi-Key | A1922-ND | 0.21 | 0.21
 | Header 2 | Header, 2-Pin | P2 | 1 | Samtec | TSW-101-07-G-D | Volume Production | Digi-Key | SAM1028-01-ND | 0.27 | 0.27
 | 27R 1% 0603(1608) | 27R 0.1W 1% 0603 (1608 Metric) SMD | R1, R2, R33, R34, R35 | 5 | Bourns | CR0603-FX-27R0ELF | Volume Production | Digi-Key | CR0603-FX-27R0ELFDKR-ND | 0.021 | 0.21
 | 1K 1% 0805(2012) | 1K 0.125W 1% 0805 (2012 Metric) SMD | R3, R5, R36, R37 | 4 | Bourns | CR0805-FX-1001ELF | Volume Production | Digi-Key | CR0805-FX-1001ELFCT-ND | 0.03 | 0.3
 | Jumper 0603(1608) | Jumper 0603 (1608 Metric) | R4, R13, R17, R18, R19, R26, R27, R28, R30 | 9 | Bourns | CR0603-J/-000ELF | Volume Production | Digi-Key | CR0603-J/-000ELFCT-ND | 0.016 | 0.16
 | 1K 1% 0603(1608) | 1K 0.1W 1% 0603 (1608 Metric) SMD | R6, R22, R24, R32 | 4 | Yageo | RC0603FR-071KL | Volume Production | Digi-Key | 311-1.00KHRDKR-ND | 0.024 | 0.24
 | 1K02 1% 0603(1608) | 1K02 0.1W 1% 0603 (1608 Metric) SMD | R7, R8, R9, R10, R40, R41 | 6 | Yageo | RC0603FR-071K02L | Volume Production | Digi-Key | 311-1.02KHRCT-ND | 0.024 | 0.24
 | 10K 5% 0402(1005) | 10K 0.063W 5% 0402 (1005 Metric) SMD | R11, R14, R15, R16, R20, R21 | 6 | Yageo | RC0402JR-0710KL | Volume Production | Digi-Key | 311-10KJRDKR-ND | 0.013 | 0.13
 | 39R 5% 0805(2012) | 39R 0.125W 5% 0805 (2012 Metric) SMD | R12 | 1 | Panasonic | ERJ-6GEYJ390V | Volume Production | Digi-Key | P39ADKR-ND | 0.1 | 0.1
 | 10K2 1% 0805(2012) | 10K2 0.125W 1% 0805 (2012 Metric) SMD | R23, R31, R38, R39 | 4 | Yageo | RC0805FR-0710K2L | Volume Production | Digi-Key | 311-10.2KCRCT-ND | 0.1 | 0.4
 | 20R 1% 0603(1608) | 20R 0.1W 1% 0603 (1608 Metric) SMD | R25 | 1 | Bourns | CR0603-FX-20R0ELF | Volume Production | Digi-Key | CR0603-FX-20R0ELFDKR-ND | 0.1 | 0.1
 | 560K 5% 0805(2012) | 560K 0.125W 5% 0805 (2012 Metric) SMD | R29 | 1 | Vishay Dale | CRCW0805560KJNEA | Volume Production | Digi-Key | 541-560KACT-ND | 0.1 | 0.1
 | 150080SS75000 | SMD mono-color Chip LED, WL-SMCW, Super Red | Red1 | 1 | Wurth Electronics | 150080SS75000 | Volume Production | Digi-Key | 732-4985-6-ND | 0.17 | 0.17
 | 104031-0811 | Micro SD Card, RA, -25 to 85 degC, 8-Pin SMD, RoHS, Tape and Reel | SD1 | 1 | Molex | 104031-0811 | Volume Production | Digi-Key | WM6357CT-ND | 2.02 | 2.02
 | AMG8833 |  | Thermal_Cam1 | 1 | Panasonic | AMG8833 | New Product | Digi-Key | P19002CT-ND | 32.5 | 32.5
 | 5019 | Test Point, 1 Position SMD, RoHS, Tape and Reel | TP1, TP2, TP3, TP4, TP5, TP6, TP7, TP8, TP9, TP10, TP11, TP12, TP13, TP14, TP15, TP16, TP17, TP18, TP19 | 19 | Keystone Electronics | 5019 | Volume Production | Digi-Key | 36-5019CT-ND | 0.331 | 6.29
 | FT234XD-R | FT234XD USB to BASIC UART IC, -40 to +85 degC, 12-Pin DFN, Pb-Free, Tape and Reel | U1 | 1 | FTDI | FT234XD-R | Volume Production | Digi-Key | 768-1178-6-ND | 2.04 | 2.04
 | BQ24075RGTRG4 | USB-Friendly Li-Ion Battery Charger and Power-Path Management IC, Vout 5.5 V, 4.3 V, -40 to 85 degC, 16-pin QFN (RGT), Green (RoHS & no Sb/Br) | U2 | 1 | Texas Instruments | BQ24075RGTT | Volume Production | Farnell | 1754755 | 2.36 | 2.36
 | 20021111-00010T4LF | CONN HEADER 10POS UNSHD VERT T/H | U3 | 1 | Amphenol FCI | 20021111-00010T4LF | Volume Production | Digi-Key | 609-3712-ND | 0.67 | 0.67
 | SAMW25H18-MR510PB | RF TXRX MODULE WIFI TRACE ANT | U4 | 1 | Microchip / Atmel | ATSAMW25H18-MR510PB | Volume Production | Digi-Key | ATSAMW25H18-MR510PB-ND | 19.15 | 19.15
 | AT25DF081A-SSH-T | IC FLASH 8MBIT 100MHZ 8SOIC | U5 | 1 | Adesto Technologies | AT25DF081A-SSH-T | Not Recommended for New Design | Digi-Key | 1265-1166-1-ND | 1.26 | 1.26
 | TLV70033DDCR | Single Output LDO, 200 mA, Fixed 3.3 V Output, 2 to 5.5 V Input, with Low IQ, 5-pin SOT (DDC), -40 to 125 degC, Green (RoHS & no Sb/Br) | U6 | 1 | Texas Instruments | TLV70033DDCR | Volume Production | Digi-Key | 296-27937-6-ND | 0.48 | 0.48
 | PKLCS1212E4001-R1 | Piezoelectric Sound Component, 4 KHz, -20 to 70 degC, 2-Pin SMD, RoHS, Tape and Reel | U7 | 1 | Murata | PKLCS1212E4001-R1 | Volume Production | Digi-Key | 490-4683-6-ND | 1.81 | 1.81
 | 14340272-32.768KHz | Crystal, 32.768 KHz, -40 to 85 degC, 3.2 x 1.5 x 0.9 mm SMD | X1 | 1 | Abracon | ABS09-32.768KHZ-T | Volume Production | Digi-Key | 535-9539-1-ND | 1.23 | 1.23
 |  |  |  |  |  |  |  |  |  | Grand Total | 126.02

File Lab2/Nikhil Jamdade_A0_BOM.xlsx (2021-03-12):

SmartEye - Smart Patient Monitoring
Component | Manufacturer Part Number | Manufacturer | Digikey | Voltage(Min) | Volatge (Max) | Interface to MCU | Qty | Cost of QTY1 | Cost QTY 1!k | Comments | DataSheet
MCU and WiFI | ATSAMW25H18-MR210PB1952 | Microchip A | ATSAMW25H18-MR210PB1952-ND | 2.7V | 4.3V | NA | 1 | 12.05 | 10.92 | ESE516 MCU and WiFi SoC | http://ww1.microchip.com/downloads/en/DeviceDoc/Atmel-42618-SmartConnect-ATSAMW25-MR210PB_Datasheet.pdf
Infrared Thermometer - MLX90614 | MLX90614ESF-BAA-000-TU | Melexis Technologies NV | MLX90614ESF-BAA-000-TU-ND | 2.6 V | 3.6 V | 2-wire SMBus interface | 1 | 14.83 | 12.47 |  | https://www.melexis.com/-/media/files/documents/datasheets/mlx90614-datasheet-melexis.pdf
Thermal Camera | AMG8833 | Panasonic Electronic Components | P19002CT-ND | 3 V | 5 V | I2C | 1 | 32.5 | 22.9 |  | https://media.digikey.com/pdf/Data%20Sheets/Panasonic%20Sensors%20PDFs/Grid-EYE_AMG88.pdf
 |  |  |  |  |  |  |  | 59.38 | 46.29 | Total with Camera option 1 in USD
 |  |  |  |  |  |  |  | #REF! | #REF! | Total with Camera option 2 in USD
 |  |  |  |  |  |  |  | 59.38 | 46.29 | Without Video Camera Module
Lithium Power Battery circuity $30-$60 |  | Not incuded in BOM

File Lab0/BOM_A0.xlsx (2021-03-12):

Component | MPN | Manufacturer | PN | Source | Min. Volt. | Max. Volt. | Power Source | Current Consumption: 50mS vibration | Current Consumption: Communicating w/ server | Current Consumption: Standby | Interface to MCU | Qty | Cost QTY1 | Cost QTY1K | Comments | Link | DS
Dev Board | ATSAMW25-XPRO | Microchip | ATSAMW25-XPRO-ND | digikey | 4.3V | 5.5V | Boost Converter (5V) | 1000 mA | 1000 mA | 1000 mA | -- | 1 | 41.04 | 40 | Does not have standby or sleep mode | Here (https://www.digikey.com/product-detail/en/microchip-technology/ATSAMW25-XPRO/ATSAMW25-XPRO-ND/5235960) | Here (http://ww1.microchip.com/downloads/en/devicedoc/Atmel-42463-SAM-W25-Xplained-Pro_UserGuide.pdf)
GPS Sensor | 746 | Adafruit | 1528-1153-ND | digikey | 3V | 4.3V | Buck Converter (3.3V) | 20 mA | 25 mA | 0 mA | UART | 1 | 39.95 | 39.95 |  | Here (https://www.digikey.com/products/en?mpart=746&v=1528) | Here (https://cdn-shop.adafruit.com/datasheets/GlobalTop-FGPMMOPA6H-Datasheet-V0A.pdf)
Vibrating Motor | 316040004 | Seeed Technology | 1597-1245-ND | digikey | 2.5V | 3.5V | Buck Converter (3.3V) | 80 mA | 0 mA | 0 mA | -- | 2 | 1.44 | 1.2 |  | Here (https://www.digikey.com/product-detail/en/seeed-technology-co-ltd/316040004/1597-1245-ND/5487673) | Here (https://media.digikey.com/pdf/Data%20Sheets/Seeed%20Technology/1027_Spec.pdf)
Haptic Driver | 2305 | Adafruit | 1528-1346-ND | digikey | 2V | 5.2V | 3.3V from MCU | .0035 mA | .0041 mA | .0041 mA | I2C pins | 2 | 7.95 | 7.95 | Voltage needs to be logic level of MCU | Here (https://www.digikey.com/product-detail/en/adafruit-industries-llc/2305/1528-1346-ND/5356831) | Here (http://www.ti.com/lit/ds/symlink/drv2605l.pdf)
LiPo battery |  |  |  |  | 3.4V | 4.2V |  |  |  |  |  | Total | 99.77 | 98.25

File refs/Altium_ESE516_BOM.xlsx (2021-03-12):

Line # | Name | Description | Designator | Quantity | Manufacturer 1 | Manufacturer Part Number 1 | Manufacturer Lifecycle 1 | Supplier 1 | Supplier Part Number 1 | Supplier Unit Price 1 | Supplier Subtotal 1
 | Servo Motor |  |  | 0 | Adafruit Industries | 1404 | Volume Production | Digi-Key | 1528-1087-ND | 0 | 0
 | PTS810 SJK 250 SMTR LFS | SWITCH TACTILE SPST-NO 0.05A 16V Tactile Switch SPST-NO Top Actuated Surface Mount | B1, B2 | 2 | ITT C&K | PTS810SJK250SMTRLFS | Volume Production | Digi-Key | CKN10503CT-ND | 0.3 | 0.6
 | CAP 4.7uF 16V 0805(2012) | CAP 4.7uF 16V ±10% 0805 (2012 Metric) Thickness 1.45mm SMD | C1, C8, C13, C14, C26 | 5 | KEMET | C0805C475K4PAC-TU | Volume Production | Digi-Key | 399-8101-6-ND | 0.27 | 1.35
 | CAP 22uF 10V 0805(2012) | CAP 22uF 10V ±20% 0805 (2012 Metric) Thickness 1mm SMD | C2 | 1 | KEMET | T529P226M010AAE200 | Volume Production | Digi-Key | 399-10534-6-ND | 1.35 | 1.35
 | CAP 10uF 16V 0805(2012) | CAP 10uF 16V ±10% 0805 (2012 Metric) Thickness 1.45mm SMD | C3, C17, C18, C19, C23 | 5 | Murata | GRM21BR61C106KE15L | Volume Production | Digi-Key | 490-3886-1-ND | 0.32 | 1.6
 | 08055C124KAT2A |  | C4 | 1 | Kyocera AVX | 08055C124KAT2A | Volume Production | Digi-Key | 478-1396-6-ND | 0.3 | 0.3
 | CAP 100nF 6.3V 0402(1005) | CAP 100nF 6.3V ±20% 0402 (1005 Metric) Thickness 0.6mm SMD | C5, C11 | 2 | KEMET | C0402C104M9PACTU | Volume Production | Digi-Key | 399-8944-6-ND | 0.1 | 0.2
 | CAP 10nF 16V 0603(1608) | CAP 10nF 16V ±10% 0603 (1608 Metric) Thickness 1mm SMD | C6 | 1 | Yageo | CC0603KRX7R7BB103 | Volume Production | Digi-Key | 311-3369-6-ND | 0.1 | 0.1
 | CAP 100nF 16V 0603(1608) | CAP 100nF 16V ±10% 0603 (1608 Metric) Thickness 1mm SMD | C7, C25 | 2 | Yageo | CC0603KRX7R7BB104 | Volume Production | Digi-Key | 311-1088-6-ND | 0.12 | 0.24
 | CAP 47pF 16V 0603(1608) | CAP 47pF 16V ±0.5pF 0603 (1608 Metric) Thickness 1mm SMD | C9, C10 | 2 | Wurth Electronics | 885012006021 | Volume Production | Digi-Key | 732-7764-1-ND | 0.1 | 0.2
 | CAP 1uF 16V 0805(2012) | CAP 1uF 16V ±20% 0805 (2012 Metric) Thickness 1mm SMD | C12, C16 | 2 | Kyocera AVX | 0805YC105KAT2A | Volume Production | Digi-Key | 478-5034-1-ND | 0.28 | 0.56
 | GRM2165C2A471JA01D |  | C15 | 1 | Murata | GRM2165C2A471JA01D | Volume Production | Digi-Key | 490-1611-6-ND | 0.26 | 0.26
 | CAP 18pF 10V 0805(2012) | CAP 18pF 10V ±1% 0805 (2012 Metric) Thickness 0.75mm SMD | C20, C21 | 2 | Vishay Vitramon | VJ0805A180GXQCW1BC | Volume Production | Digi-Key | 720-1709-6-ND | 0.29 | 0.58
 | CAP 1uF 16V 0603(1608) | CAP 1uF 16V ±10% 0603 (1608 Metric) Thickness 1mm SMD | C22 | 1 | Kyocera AVX | 0603YC105KAT2A | Volume Production | Digi-Key | 478-5010-6-ND | 0.26 | 0.26
 | CC0603MRX5R5BB226 | Multilayer Ceramic Capacitor, 22 uF, +/- 20%, 6.3 V, -55 to 85 degC,0603 (1608 Metric), RoHS, Tape and Reel | C24 | 1 | TDK | C1608X5R0J226M080AC | Volume Production | Digi-Key | 445-8028-1-ND | 0.48 | 0.48
 | PRTR5V0U2X,215 | Ultra Low Capacitance Double Rail-to-Rail ESD Protection Diode, 5.5 V, 1 pF, -40 to 85 degC, 4-Pin SOT143B, RoHS, Tape and Reel | D1 | 1 | NXP Semiconductors | PRTR5V0U2X,215 | Volume Production | Digi-Key | 1727-3884-1-ND | 0.55 | 0.55
 | LTST-C170CKT | LED RED CLEAR 0805 SMD | D2, D4 | 2 | Vishay Lite-On | LTST-C170CKT | Volume Production | Digi-Key | 160-1176-6-ND | 0.38 | 0.76
 | LTST-C170GKT | LED Uni-Color Green, 100 mW, 120 mA, -55 to 85 degC, 2-Pin SMD, RoHS, Tape and Reel | D3 | 1 | Vishay Lite-On | LTST-C170GKT | Volume Production | Digi-Key | 160-1179-6-ND | 0.33 | 0.33
 | LTST-C191KGKT | Chip LED, Green, 574 nm, 40 pF, -55 to 85 degC, 2-Pin SMD, RoHS, Tape and Reel | DS1, DS2 | 2 | Vishay Lite-On | LTST-C191KGKT | Volume Production | Digi-Key | 160-1446-1-ND | 0.29 | 0.58
 | BLM21PG221SN1D | Chip Ferrite Bead for Power Lines, 220 Ohm, 2000 mA, -55 to 125 degC, 2 x 1.25 x 1.05 mm SMD, Tape and Reel | FB1 | 1 | Murata | BLM21PG221SN1D | Volume Production | Digi-Key | 490-1054-6-ND | 0.1 | 0.1
 | ZX62R-B-5P | Connector; USBMicro-B,Reverse type, SMT; 5 Position; Right Angle | J1 | 1 | Hirose | ZX62R-B-5P(30) | Volume Production | Digi-Key | H125274CT-ND | 1.02 | 1.02
 | SDR0403-1R0ML | SDR0403 Series Power Inductor, 1 uF +/- 20 %, 0.033 Ohm, -40 to 125 degC, 2-Pin SMD, RoHS, Tape and Reel | L1 | 1 | Bourns | SDR0403-1R0ML | Volume Production | Digi-Key | SDR0403-1R0MLDKR-ND | 0.6 | 0.6
 | 74438323010 | Power Multilayer Inductor WE-MAPI, L=1.0µH | L2 | 1 | Wurth Electronics | 74438323010 | Volume Production | Digi-Key | 732-4843-1-ND | 1.13 | 1.13
 | 640456-4 | Male Header, Pitch 2.54 mm, 1 x 4 Position, Height 10.03 mm, Tail Length 3.56 mm, RoHS, Bulk | P1 | 1 | TE Connectivity | 640456-4 | Volume Production | Digi-Key | A1922-ND | 0.21 | 0.21
 | 640456-2 | CONN HEADER VERT 2POS .100 TIN | P2 | 1 | AMP - TE CONNECTIVITY | 640456-2 | Unknown | Digi-Key | A1921-ND | 0.11 | 0.11
 | MTSW-104-07-L-S-170 | Modified .025" SQ Post Header, Through-hole, Vertical, -55 to 125 degC, 2.54 mm Pitch, 4-Pin, Male, RoHS | P3, P5 | 2 | Samtec | MTSW-104-07-L-S-170 | Unknown
 | MTLW-105-05-L-S-190 | Low Profile .025" SQ Post Header, Through-hole, Vertical, -55 to 125 degC, 2.54 mm Pitch, 5-Pin, Male, RoHS | P4 | 1 | Samtec | MTLW-105-05-L-S-190 | Unknown | Newark | 40AC2495 | 0.928 | 0.928
 | BC846ALT1G | General Purpose Transistor, NPN Silicon, 3-Pin SOT-23, Pb-Free, Tape and Reel | Q1 | 1 | ON Semiconductor | BC846ALT1G | Volume Production | Digi-Key | BC846ALT1GOSCT-ND | 0.12 | 0.12
 | 453K 1% 0805(2012) | 453K 0.125W 1% 0805 (2012 Metric) SMD | R1 | 1 | Yageo | RC0805FR-07453KL | Volume Production | Digi-Key | 311-453KCRDKR-ND | 0.1 | 0.1
 | 120K 5% 0805(2012) | 120K 0.125W 5% 0805 (2012 Metric) SMD | R2 | 1 | Yageo | RC0805JR-07120KL | Volume Production | Digi-Key | 311-120KARDKR-ND | 0.1 | 0.1
 | 27R 1% 0603(1608) | 27R 0.1W 1% 0603 (1608 Metric) SMD | R3, R4, R34, R35, R36 | 5 | Yageo | RC0603FR-0727RL | Volume Production | Digi-Key | 311-27.0HRCT-ND | 0.024 | 0.24
 | 1K 1% 0603(1608) | 1K 0.1W 1% 0603 (1608 Metric) SMD | R5, R7, R27, R33 | 4 | Yageo | RC0603FR-071KL | Volume Production | Digi-Key | 311-1.00KHRDKR-ND | 0.024 | 0.24
 | Jumper 0603(1608) | Jumper 0603 (1608 Metric) | R6, R16, R20, R21, R22, R28, R42 | 7 | Bourns | CR0603-J/-000ELF | Volume Production | Digi-Key | CR0603-J/-000ELFCT-ND | 0.016 | 0.16
 | 1K02 1% 0603(1608) | 1K02 0.1W 1% 0603 (1608 Metric) SMD | R8, R9, R10, R11, R40 | 5 | Yageo | RC0603FR-071K02L | Volume Production | Digi-Key | 311-1.02KHRCT-ND | 0.024 | 0.24
 | 10K2 1% 0805(2012) | 10K2 0.125W 1% 0805 (2012 Metric) SMD | R12, R29, R30, R31, R32 | 5 | Yageo | RC0805FR-0710K2L | Volume Production | Digi-Key | 311-10.2KCRCT-ND | 0.042 | 0.42
 | ERJ8BWFR010V |  | R13 | 1 | Panasonic | ERJ8BWFR010V | Volume Production | Digi-Key | P.010AUDKR-ND | 0.74 | 0.74
 | 10K 5% 0402(1005) | 10K 0.063W 5% 0402 (1005 Metric) SMD | R14, R17, R18, R19, R23, R24, R43 | 7 | Yageo | RC0402JR-0710KL | Volume Production | Digi-Key | 311-10KJRDKR-ND | 0.013 | 0.13
 | 39R 5% 0805(2012) | 39R 0.125W 5% 0805 (2012 Metric) SMD | R15, R44 | 2 | Panasonic | ERJ-6GEYJ390V | Volume Production | Digi-Key | P39ADKR-ND | 0.1 | 0.2
 | ERJ-6ENF1002V |  | R25, R26 | 2 | Panasonic | ERJ6ENF1002V | Volume Production | Digi-Key | P10.0KCCT-ND | 0.1 | 0.2
 | 5K49 1% 0805(2012) | 5K49 0.125W 1% 0805 (2012 Metric) SMD | R37, R38, R39 | 3 | Panasonic | ERJ-6ENF5491V | Volume Production | Digi-Key | P5.49KCDKR-ND | 0.1 | 0.3
 | 220R 5% 0805(2012) | 220R 0.125W 5% 0805 (2012 Metric) SMD | R41 | 1 | Panasonic | ERJ6GEYJ221V | Volume Production | Digi-Key | P220ADKR-ND | 0.1 | 0.1
 | 150080SS75000 | SMD mono-color Chip LED, WL-SMCW, Super Red | Red1 | 1 | Wurth Electronics | 150080SS75000 | Volume Production | Digi-Key | 732-4985-6-ND | 0.17 | 0.17
 | 104031-0811 | Micro SD Card, RA, -25 to 85 degC, 8-Pin SMD, RoHS, Tape and Reel | SD1 | 1 | Molex | 104031-0811 | Volume Production | Digi-Key | WM6357CT-ND | 2.02 | 2.02
 | 5019 | Test Point, 1 Position SMD, RoHS, Tape and Reel | TP1, TP2, TP3, TP4, TP5, TP6, TP7, TP8, TP9, TP10, TP11, TP12, TP13, TP14, TP15, TP16, TP17, TP18, TP19, TP20 | 20 | Keystone Electronics | 5019 | Volume Production | Digi-Key | 36-5019CT-ND | 0.331 | 6.62
 | TLV62569ADRLR |  | U1 | 1 | Texas Instruments | TLV62569ADRLR | Unknown | Digi-Key | 296-51692-1-ND | 1.32 | 1.32
 | TPS61232DRCT |  | U2 | 1 | Texas Instruments | TPS61232DRCT | Volume Production | Digi-Key | 296-37990-1-ND | 2.92 | 2.92
 | FT234XD-R | FT234XD USB to BASIC UART IC, -40 to +85 degC, 12-Pin DFN, Pb-Free, Tape and Reel | U3 | 1 | FTDI | FT234XD-R | Volume Production | Digi-Key | 768-1178-6-ND | 2.04 | 2.04
 | BQ24075RGTRG4 | USB-Friendly Li-Ion Battery Charger and Power-Path Management IC, Vout 5.5 V, 4.3 V, -40 to 85 degC, 16-pin QFN (RGT), Green (RoHS & no Sb/Br) | U4 | 1 | Texas Instruments | BQ24075RGTT | Volume Production | Digi-Key | 296-23840-6-ND | 2.67 | 2.67
 | BQ27441DRZR-G1A |  | U5 | 1 | Texas Instruments | BQ27441DRZR-G1A | Volume Production | Digi-Key | 296-39941-1-ND | 2.62 | 2.62
 | 20021111-00010T4LF | CONN HEADER 10POS UNSHD VERT T/H | U6 | 1 | Amphenol FCI | 20021111-00010T4LF | Volume Production | Digi-Key | 609-3712-ND | 0.67 | 0.67
 | SAMW25H18-MR510PB | RF TXRX MODULE WIFI TRACE ANT | U7 | 1 | Microchip | ATSAMW25H18-MR510PB | Unknown | Digi-Key | ATSAMW25H18-MR510PB-ND | 19.15 | 19.15
 | AT25DF081A-SSH-T | IC FLASH 8MBIT 100MHZ 8SOIC | U8 | 1 | Adesto Technologies | AT25DF081A-SSH-T | Not Recommended for New Design | Digi-Key | 1265-1166-1-ND | 1.26 | 1.26
 | OPA337UA/2K5 | MicroSIZE, Single-Supply CMOS Operational Amplifier MicroAmplifier(TM) Series, 2.5 to 5.5 V, -40 to 85 degC, 8-pin SOIC (D8), Green (RoHS & no Sb/Br) | U10 | 1 | Texas Instruments | OPA337UA/2K5 | Volume Production | Digi-Key | OPA337UADKR-ND | 0.78 | 0.78
 | PKLCS1212E4001-R1 | Piezoelectric Sound Component, 4 KHz, -20 to 70 degC, 2-Pin SMD, RoHS, Tape and Reel | U11 | 1 | Murata | PKLCS1212E4001-R1 | Volume Production | Digi-Key | 490-4683-6-ND | 1.81 | 1.81
 | 14340272-32.768KHz | Crystal, 32.768 KHz, -40 to 85 degC, 3.2 x 1.5 x 0.9 mm SMD | X1 | 1 | Abracon | ABS09-32.768KHZ-T | Volume Production | Digi-Key | 535-9539-1-ND | 1.23 | 1.23

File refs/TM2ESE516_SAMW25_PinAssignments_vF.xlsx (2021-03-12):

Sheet: Updated BOM
Team Name
Component | Manufacturer Part Number | Manufacturer | Digikey | Voltage(Min) | Volatge (Max) | Interface to MCU | Power Source | Current Consumption in operating mode | Current Consumption in Stand by mode | Qty | Cost of QTY1 | Cost QTY 1!k | Comments | DataSheet
MCU and WiFI | ATSAMW25H18-MR210PB1952 | Microchip A | ATSAMW25H18-MR210PB1952-ND | 2.7V | 4.3V | NA | 3.3V Buck Convertor | 4.92 mA (SAMD21) + 230mA (winc1500) | 4.92 mA (SAMD21) + 230mA (winc1500) | 1 | 12.05 | 10.92 | ESE516 MCU and WiFi SoC | http://ww1.microchip.com/downloads/en/DeviceDoc/Atmel-42618-SmartConnect-ATSAMW25-MR210PB_Datasheet.pdf
Infrared Thermometer - MLX90614 | MLX90614ESF-BAA-000-TU | Melexis Technologies NV | MLX90614ESF-BAA-000-TU-ND | 2.6 V | 3.6 V | 2-wire SMBus interface | 3.3V Buck Convertor | 1.5 mA | 2.5 uA | 1 | 14.83 | 12.47 |  | https://www.melexis.com/-/media/files/documents/datasheets/mlx90614-datasheet-melexis.pdf
Thermal Camera | AMG8833 | Panasonic Electronic Components | P19002CT-ND | 3 V | 5 V | I2C | 3.3V Buck/ 5V boost Convertor | 4.5 mA | 0.8 mA Standby Mode 0.2 mA sleep mode | 1 | 32.5 | 22.9 |  | https://media.digikey.com/pdf/Data%20Sheets/Panasonic%20Sensors%20PDFs/Grid-EYE_AMG88.pdf
Servo Motor | 1404 | Adafruit Industries LLC | 1528-1087-ND | 4.8V | 7.2V | PWM | 5V Boost Convertor | 150 mA | 15mA | 1 | 14.95 | 14.95 |  | https://www.digikey.com/product-detail/en/adafruit-industries-llc/1404/1528-1087-ND/5154662 | https://www.mouser.com/pdfdocs/900-00360-Feedback-360-HS-Servo-v12.pdf | https://media.digikey.com/pdf/Data%20Sheets/DFRobot%20PDFs/SER0044_Web.pdf
LED and Buzzer Circuit |  |  |  | 1.5 V | 3.3 V | GPIO |  | 20 mA x 5
 |  |  |  |  |  |  |  |  |  |  | 74.33 | 61.24
Lithium Power Battery circuity $30-$60 |  | Not incuded in BOM | Lithium Polymer Batttery - 3.7V 2500MAH | Lithium Polymer Battery Battery- 3.7V 1200MAH
 |  |  | Battery Range 3V to 4.3 volts
 |  |  | This is 1 cell (S) battery. A sthe number of cells increses the nominal voltage increases e.g 2S =7.4 V, 3S =11.1V etc

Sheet: PIN PLACEMENT
Group Name | Example Dream Team | TM2
MEMBER A | Nikhil Jamdade
MEMBER B | Sheil Sarda
 |  | MUST BE THE SAME!
 |  |  |  | INFORMATION RELATED TO OUR DEVICE |  |  | COMMENTS
PIN # | Pin Description | Function | Function on SAMW25 Dev Board | Function on our device | Peripheral used, if applicable | Component connected to device:
1 | GND | Common ground | Common ground | Provide Common ground terminal to every device |  | Thermal Camera ground, IR Sensor ground, power supply ground
2 | UART_TxD | Currently used only for Atmel debug. Not for customer use. Leave unconnected. |  | Leave unconnected. |  | Leave unconnected.
3 | UART_RxD | Currently used only for Atmel debug. Not for customer use. Leave unconnected. |  | Leave unconnected. |  | Leave unconnected.
4 | Wi-Fi Chip_En | Currently used only for Atmel debug. Not for customer use. Leave unconnected. |  | Leave unconnected. |  | Leave unconnected.
5 | Wi-Fi GPIO_1/RTC | Currently used only for Atmel debug. Not for customer use. Leave unconnected. |  | Leave unconnected. |  | Leave unconnected.
6 | Wi-Fi GPIO_3 | ATWINC1500 General purpose I/O
7 | VBAT | Supply for Wi-Fi RF Power Amplifier and Internal 1.3V Switching Regulator
8 | PA16 | See SAM D21G datasheet | SERCOM1 PAD[0] SPI MISO (External Flash) |  | SERCOM 1 | AT25DF081A-SSH-T
9 | PA17 | See SAM D21G datasheet | I2C EXTINT[1] SERCOM5/ PAD[1] TC6/WO[1] TCC0/ WO[5] I2S/ MCK[0] GCLK_IO[3] | SCL, I2C | SERCOM3 | Teperature Sensor MLX90614
10 | GND
11 | PA18 | See SAM D21G datasheet | SERCOM1 PAD[2] SPI MOSI (External Flash) |  | SERCOM 1 | AT25DF081A-SSH-T
12 | PA19 | See SAM D21G datasheet | SERCOM1 PAD[3] SPI SCK (External Flash) |  | SERCOM 1 | AT25DF081A-SSH-T
13 | PA20 | See SAM D21G datasheet | VDDIO EXTINT[4] X[8] SERCOM5/ PAD[2] SERCOM3/ PAD[2] TC7/WO[0] TCC0/ WO[6] I2S/ SCK[0] GCLK_IO[4] | External Interrupt | EXTINT[4] | Thermal Camera
14 | PA21 | See SAM D21G datasheet |  |  |  | BQ_EN1
15 | PA22 | See SAM D21G datasheet | I2C EXTINT[6] X[10] SERCOM3/ PAD[0] SERCOM5/ PAD[0] TC4/WO[0] TCC0/ WO[4] GCLK_IO[6] | SDA, I2C | SERCOM3 | Terperature Sensor MLX90614
16 | PA23 | See SAM D21G datasheet | Yellow LED1 |  | GPIO (Output)
17 | GND
18 | PA24/USB_DM | Host Interface USB Data minus pin | USB D-, EXTINT[12] SERCOM3/ PAD[2] SERCOM5/ PAD[2] TC5/WO[0] TCC1/ WO[2] | PWM out | TC peripheral | Servo Motor
19 | PA25/USB_DP | Host Interface USB Data Plus pin | USB D+, EXTINT[13] SERCOM3/ PAD[3] SERCOM5/ PAD[3] TC5/WO[1] TCC1/ WO[3] USB/DP | PWM in | TC Peripheral | Servo Motor
20 | GND | Ground
21 | VCC | Power supply for I/O
22 | PB22 | See SAM D21G datasheet |  |  |  | BQ_EN1
23 | PB23 | See SAM D21G datasheet | SW0 (Button on Board)
24 | RESET_N | System Reset. Low level on this pin resets the entire module. |  |  |  | Reset (Connect to a button for reset with safety pull-up)
25 | PA30/SWCLK | Cortex Serial Wire Debug Interface CLK | SWD clock |  | Programming (SWD) | Programming (SWD)
26 | PA31/SWDIO | Cortex Serial Wire Debug Interface Data I/O | SWD data |  | Programming (SWD) | Programming (SWD)
27 | PB02 | See SAM D21G datasheet
28 | PB03 | See SAM D21G datasheet
29 | PA00/GPIO/XIN32 | See SAM D21G datasheet | XIN32 |  | 32 kHz Clock | 32 kHz Clock
30 | PA01/GPIO/XOUT32 | See SAM D21G datasheet | XOUT32 |  | 32 kHz Clock | 32 kHz Clock
31 | PA02 | See SAM D21G datasheet | EXTINT[2] AIN[0] PTC.DAC | Converting Analong signal into digital | DAC | Servo Motor
32 | GND | Ground
33 | PA03 | See SAM D21G datasheet
34 | PA04 | See SAM D21G datasheet | USB ID | PWM fo buzzer | TCC0 | Buzzer
35 | PA05 | See SAM D21G datasheet | VBUS Detection
36 | PA06 | See SAM D21G datasheet |  |  |  | INT_Guage
37 | PA07 | See SAM D21G datasheet | GPIO for Onboard Serial Flash |  | GPIO (Output)
38 | PA08 | See SAM D21G datasheet | I2C NMI AIN[16] X[0] SERCOM0/ PAD[0] SERCOM2/ PAD[0] TCC0/WO[0] TCC1/ WO[2] I2S/SD[1] | Serial SDA, I2C Master driver in synchronous - SCL | SERCOM0, I2C | Thermal Camera AMG8833 SCL
39 | PA09 | See SAM D21G datasheet | I2C EXTINT[9] AIN[17] X[1] SERCOM0/ PAD[1] SERCOM2/ PAD[1] TCC0/WO[1] TCC1/ WO[3] I2S/ MCK[0] | Serial Clock, I2C Master driver in synchronous- SDA | SERCOM0,I2C | Thermal Camera AMG8833 SDA
40 | PA10 | See SAM D21G datasheet
41 | PA11 | See SAM D21G datasheet
42 | GND | Ground
43 | PB10 | See SAM D21G datasheet | SERCOM4 PAD[3] UART RX EDGB |  | SERCOM 4
44 | PB11 | See SAM D21G datasheet | SERCOM4 PAD[2] UART TX EDGB |  | SERCOM 4
45 | Wi-Fi GPIO_4 | ATWINC1500 General purpose I/O
46 | Wi-Fi GPIO_5 | ATWINC1500 General purpose I/O
47 | Wi-Fi GPIO_6 | ATWINC1500 General purpose I/O
48 | Wi-Fi I2C_SCL | Currently used only for Atmel debug. Not for customer use. Leave unconnected. |  | Leave unconnected. |  | Leave unconnected.
49 | Wi-Fi I2C_SDA | Currently used only for Atmel debug. Not for customer use. Leave unconnected. |  | Leave unconnected. |  | Leave unconnected.
50 | Wi-Fi Reset_n | Currently used only for Atmel debug. Not for customer use. Leave unconnected. |  | Leave unconnected. |  | Leave unconnected.
51 | GND | Ground

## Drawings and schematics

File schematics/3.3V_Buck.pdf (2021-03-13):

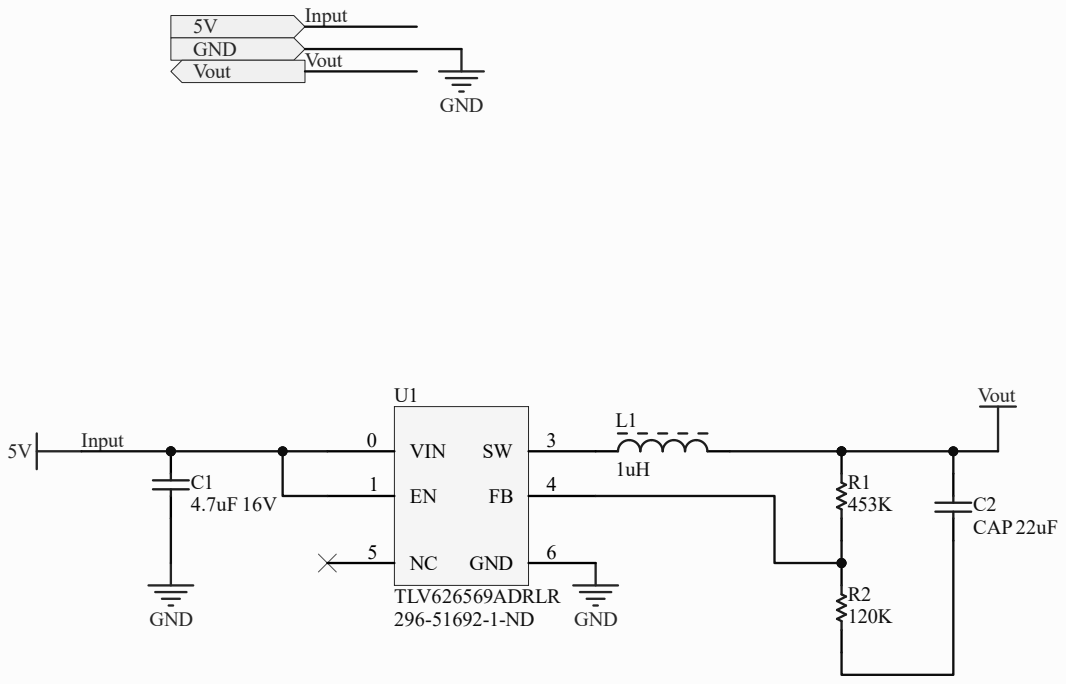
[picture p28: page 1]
Title; Size; Number; Revision; Date:; Sheet of; File:; \\..\3.3VBuck.SchDoc; Drawn By:; 5V GND Vout; Input; Vout; GND; C2 CAP 22uF; VIN 0; TLV626569ADRLR

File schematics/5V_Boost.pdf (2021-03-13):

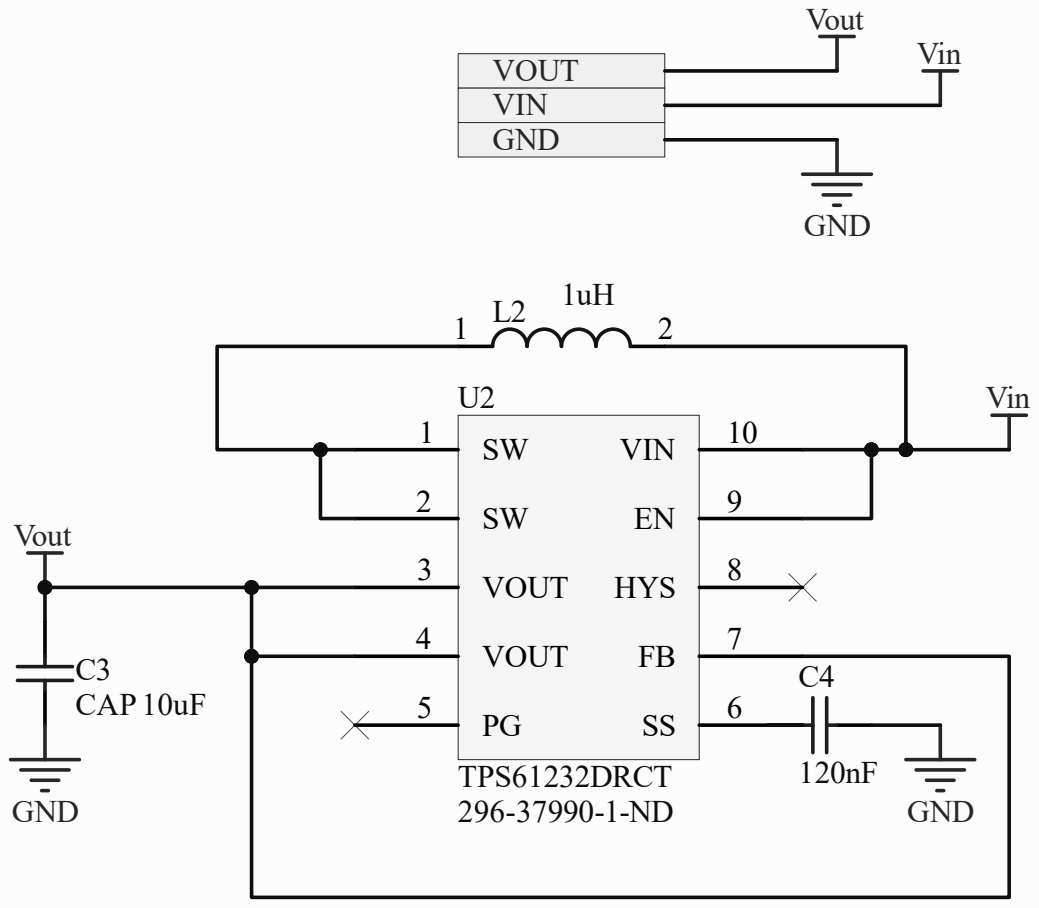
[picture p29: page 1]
Title; Size; Number; Revision; Date:; Sheet of; File:; \\..\5vBoost.SchDoc; Drawn By:; VOUT VIN GND; Vout; Vin; GND; C3 CAP 10uF; VOUT 3; VOUT 4; VIN; HYS; TPS61232DRCT

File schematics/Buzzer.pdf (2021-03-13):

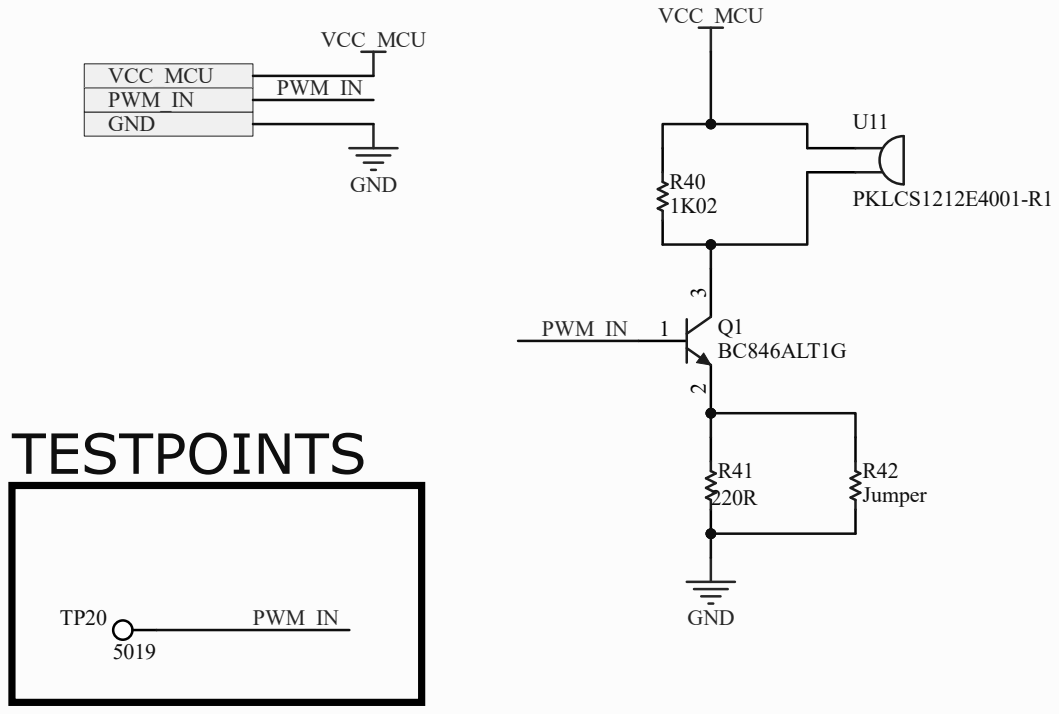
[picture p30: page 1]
Title; Size; Number; Revision; Date:; Sheet of; File:; \\..\Buzzer.SchDoc; Drawn By:; Q1 BC846ALT1G; GND; PKLCS1212E4001-R1; VCC_MCU; PWM_IN; R42 Jumper; TESTPOINTS

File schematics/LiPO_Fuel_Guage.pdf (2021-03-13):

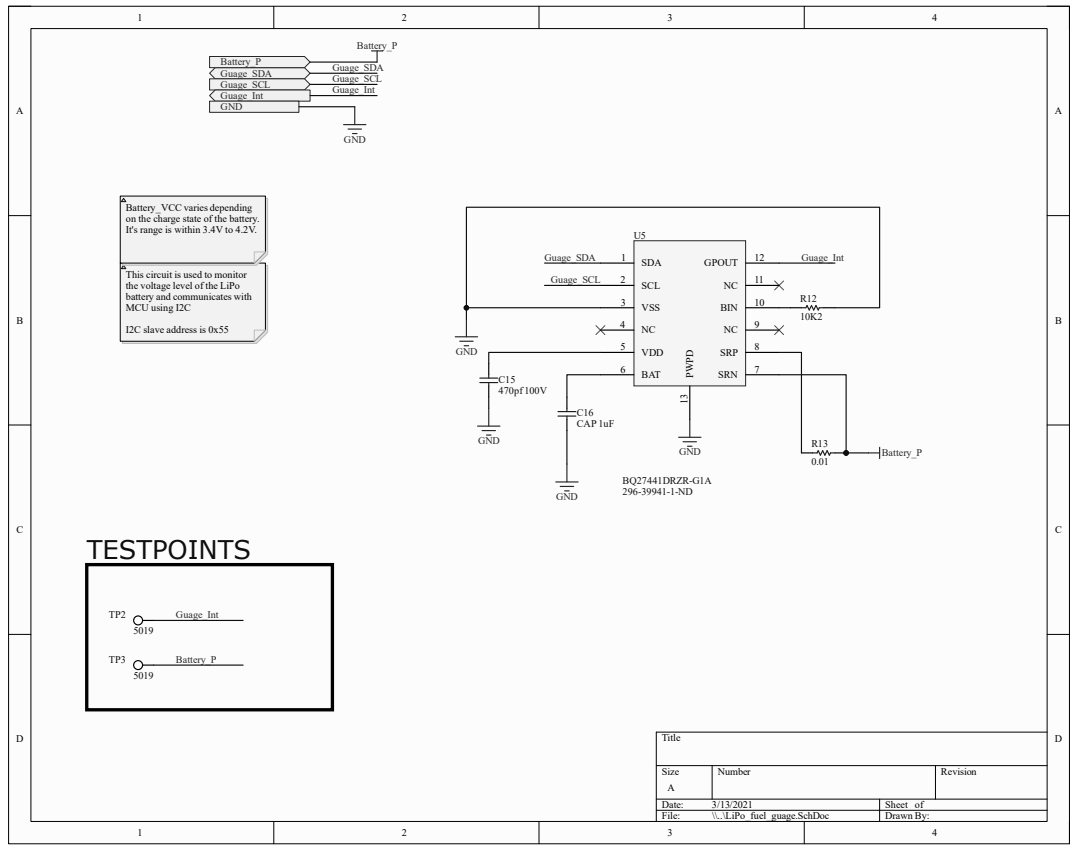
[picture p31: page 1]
Title; Size; Number; Revision; Date:; Sheet of; File:; \\..\LiPo_fuel_guage.SchDoc; Drawn By:; Guage_SCL; Guage_SDA; Guage_SDA Guage_SCL Guage_Int; TESTPOINTS; Guage_Int; Battery_P; C16 CAP 1uF; GND; GPOUT; BIN; SRP; BAT 6; SDA 1; VSS 3; SCL 2; SRN; VDD 5; 11 PWPD 13; BQ27441DRZR-G1A

Battery_VCC varies depending
on the charge state of the battery.
It's range is within 3.4V to 4.2V.

This circuit is used to monitor
the voltage level of the LiPo
battery and communicates with
MCU using I2C

I2C slave address is 0x55

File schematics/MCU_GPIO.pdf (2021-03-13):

GND | 32 PA03 | 33 PA04 | 34 PA05 | 35 PA06 | 36 PA07 | 37 PA08 | 38 PA09 | 39 PA10 | 40 PA11 | 41 GND | 42 PB10 | 43 PB11 | 44 GPIO 15/4 | 45 GPIO 16/5 | 46 GPIO 18/6 | 47 I2C SCL | 48 I2C SDA | 49 RESETN WIFI | 50 GND | 51
XIN_32 | XIN_32 XOUT_32

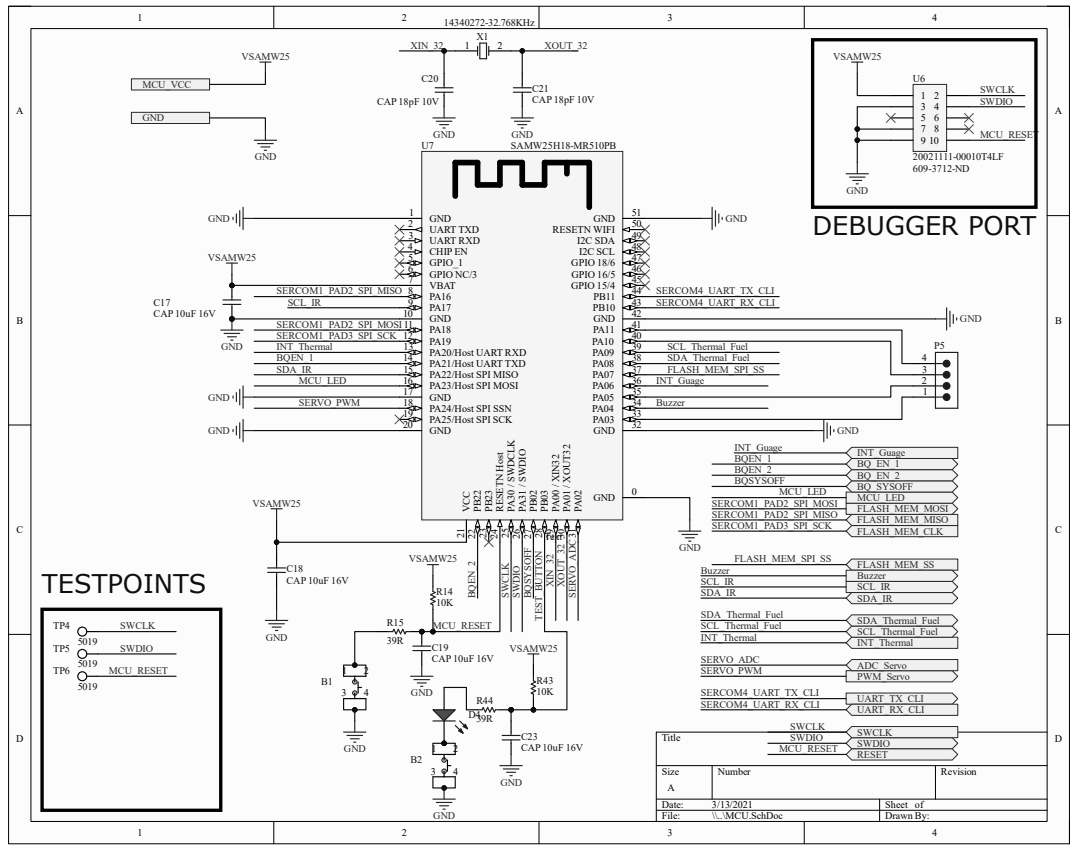
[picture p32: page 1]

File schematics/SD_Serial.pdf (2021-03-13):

# AT25_WP AT²⁵_CSSERIAL FLASH

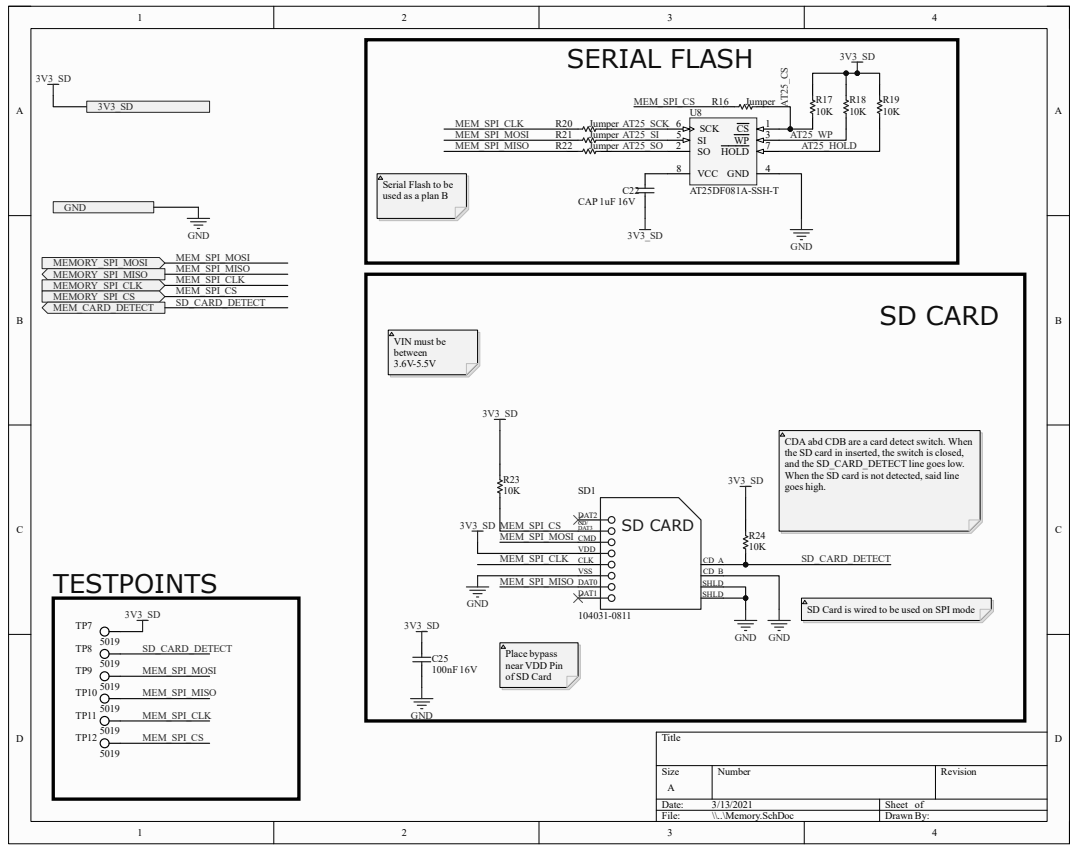
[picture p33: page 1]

Serial Flash to be
used as a plan B

CDA abd CDB are a card detect switch. When
the SD card in inserted, the switch is closed,
and the SD_CARD_DETECT line goes low.
When the SD card is not detected, said line
goes high.

SD Card is wired to be used on SPI mode

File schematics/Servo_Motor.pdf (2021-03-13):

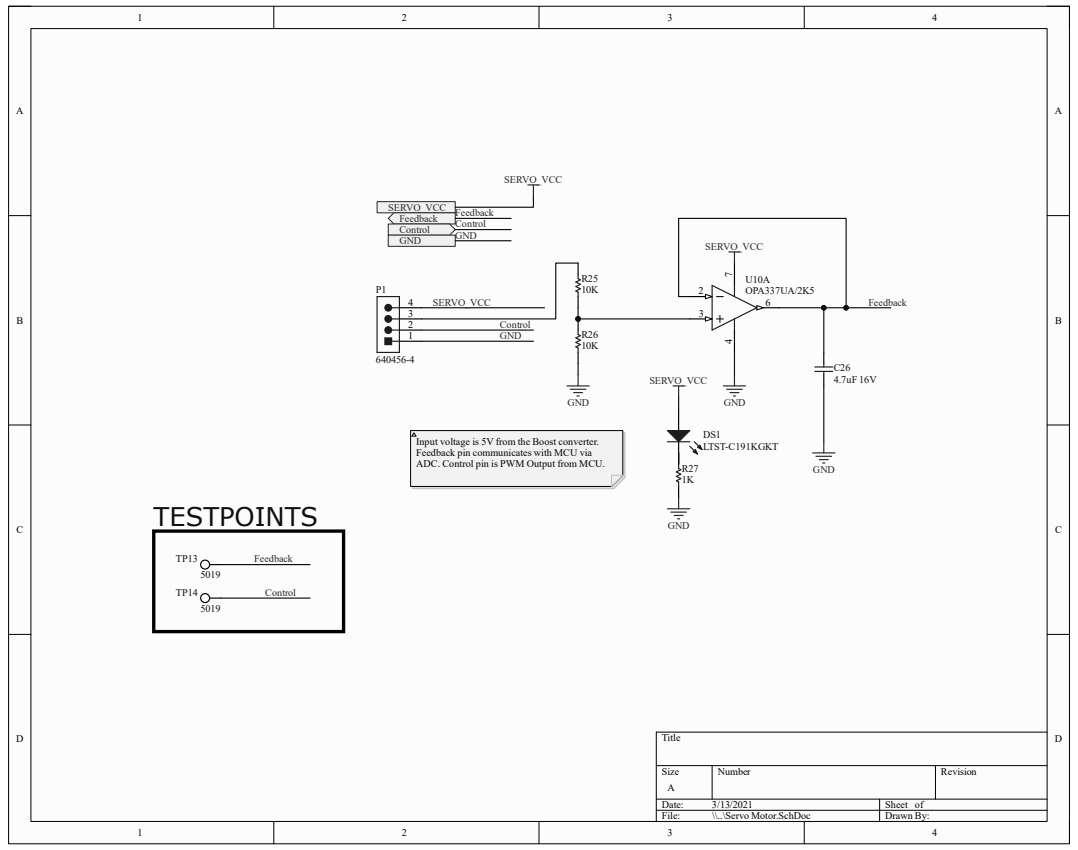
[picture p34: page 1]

Input voltage is 5V from the Boost converter.
Feedback pin communicates with MCU via
ADC. Control pin is PWM Output from MCU.

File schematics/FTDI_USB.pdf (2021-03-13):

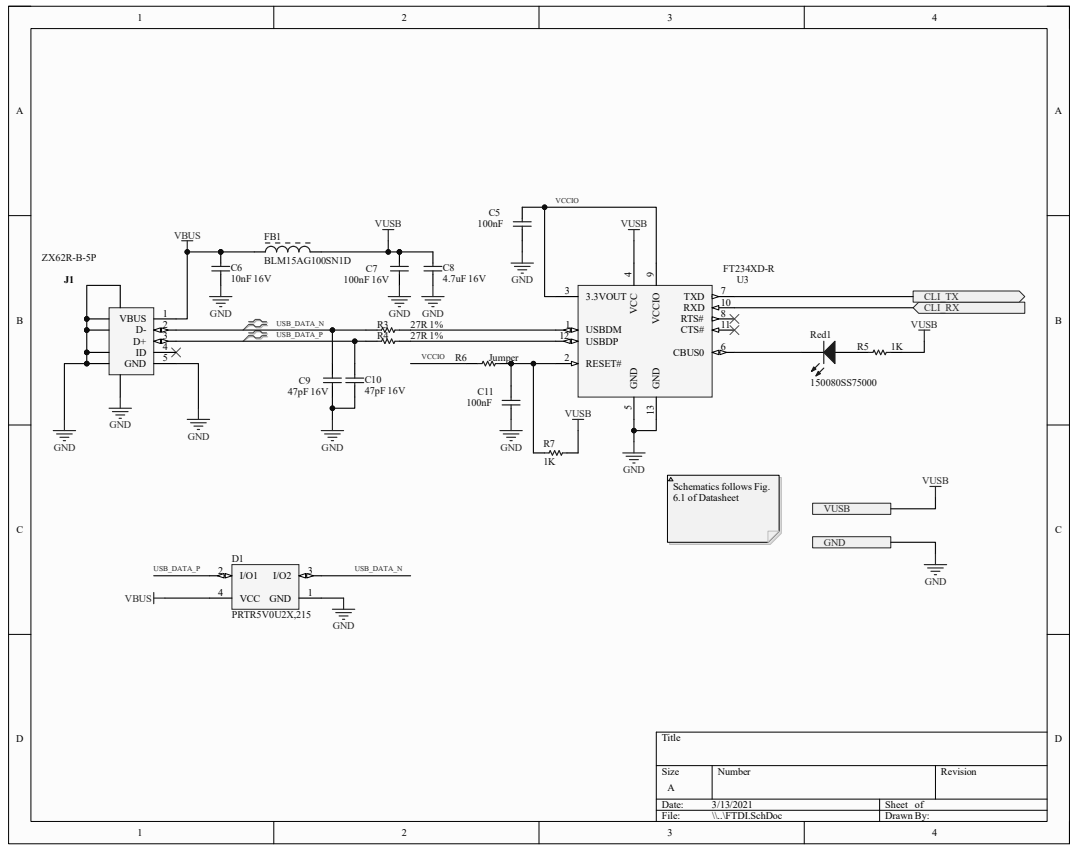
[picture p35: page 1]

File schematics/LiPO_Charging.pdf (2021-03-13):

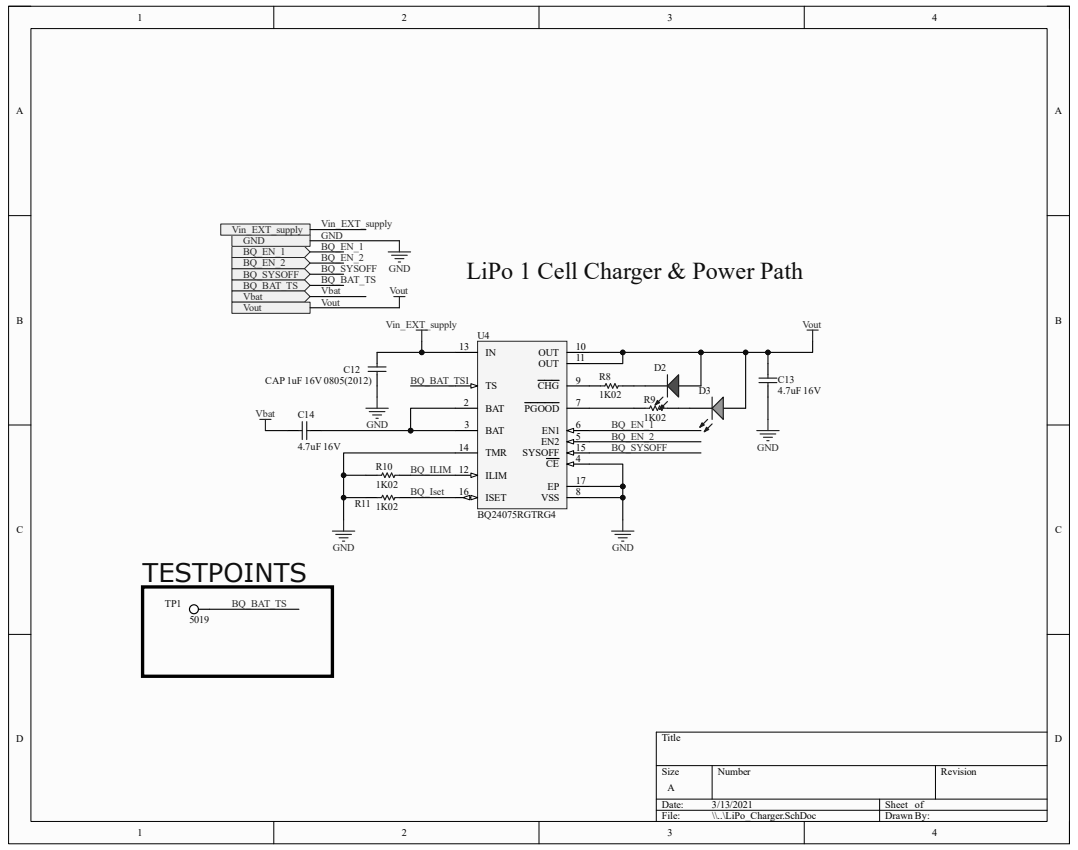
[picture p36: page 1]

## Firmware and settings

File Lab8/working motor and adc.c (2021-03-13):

#include <errno.h>
#include "asf.h"
#include "main.h"
#include "stdio_serial.h"
#include "driver/include/m2m_wifi.h"
#include "socket/include/socket.h"
#include "iot/http/http_client.h"
#include "MQTTClient/Wrapper/mqtt.h"
#include "SerialConsole/SerialConsole.h"

#define STRUCT_START_ADDRESS ((uint32_t)(0xAD00))

#define STRING_EOL                      "\r\n"
#define STRING_HEADER                   "-- HTTP file downloader example --"STRING_EOL \
"-- "BOARD_NAME " --"STRING_EOL	\
"-- Compiled: "__DATE__ " "__TIME__ " --"STRING_EOL


#define CONF_PWM_MODULE      TCC0
#define CONF_PWM_CHANNEL     2
#define CONF_PWM_OUTPUT      2
#define CONF_PWM_OUT_PIN     PIN_PA10F_TCC0_WO2
#define CONF_PWM_OUT_MUX     MUX_PA10F_TCC0_WO2
#define ADC_TEMP_SAMPLE_LENGTH	4

volatile char buffer[7];
struct tcc_module tcc_instance;
struct tcc_config config_tcc;
/* Structure for ADC module instance */
struct adc_module adc_instance;
/* Structure for USART module instance */
struct usart_module console_instance;
/*  To Store ADC output in voltage format */
float result;
/* To store raw_result of ADC output */
uint16_t raw_result;
/* To read the STATUS register of ADC */
uint8_t status;
// used for the conversion of user input pin to int for use in processing
int pin_value[10];

uint32_t currentIP = 0x0000;
volatile char mqtt_msg [64]= "{\"d\":{\"temp\":17}}\"";
volatile char loc_msg [256]= "{\"d\":{\"loc\":{\"lat\":20,\"long\":40}}}\"";
volatile char img_msg [256];
volatile char batt_msg [64]= "{\"d\":{\"batt\":17}}\"";
volatile char servo_msg [128]= "{\"d\":{\"servo\":17}}\"";
volatile char fw_msg [64]= "true";

volatile bool updateReady = false;

char * crc32_string;
uint32_t ver = 0x00;
char metadata_file_name[] = "0:metadata.txt";

volatile uint32_t dummyData = 1;
Status * currentStatus;
enum status_code error_code;




/*HTTP DOWNLOAD RELATED DEFINES AND VARIABLES*/

uint8_t do_download_flag = false; //Flag that when true initializes a download. False to connect to MQTT broker
/** File download processing state. */
static download_state down_state = NOT_READY;
/** SD/MMC mount. */
static FATFS fatfs;
/** File pointer for file download. */
static FIL file_object;
/** Http content length. */
static uint32_t http_file_size = 0;
/** Receiving content length. */
static uint32_t received_file_size = 0;
/** File name to download. */
static char save_file_name[MAIN_MAX_FILE_NAME_LENGTH + 1] = "0:";

// LED state variable
bool ledOn = false;

/** UART module for debug. */
static struct usart_module cdc_uart_module;

/** Instance of Timer module. */
struct sw_timer_module swt_module_inst;

/** Instance of HTTP client module. */
struct http_client_module http_client_module_inst;

/*MQTT RELATED DEFINES AND VARIABLES*/

/** User name of chat. */
char mqtt_user[64] = "Unit1";

/* Instance of MQTT service. */
static struct mqtt_module mqtt_inst;

/* Receive buffer of the MQTT service. */
static unsigned char mqtt_read_buffer[MAIN_MQTT_BUFFER_SIZE];
static unsigned char mqtt_send_buffer[MAIN_MQTT_BUFFER_SIZE];

#define DATA_LENGTH 256
static uint16_t i2c_buffer[DATA_LENGTH];

#define SLAVE_ADDRESS 0x69

struct i2c_master_module i2c_master_instance;
struct i2c_master_packet packet;

void configure_i2c(void)
{
	/* Initialize config structure and software module */
	struct i2c_master_config config_i2c_master;
	i2c_master_get_config_defaults(&config_i2c_master);
	config_i2c_master.pinmux_pad0       = PINMUX_PA08C_SERCOM0_PAD0;
	config_i2c_master.pinmux_pad1       = PINMUX_PA09C_SERCOM0_PAD1;

	/* Change buffer timeout to something longer */
	config_i2c_master.buffer_timeout = 65535;
	/* Initialize and enable device with config */
	while(i2c_master_init(&i2c_master_instance, SERCOM0, &config_i2c_master) != STATUS_OK);
	
	i2c_master_enable(&i2c_master_instance);
}
void i2c_write_complete_callback(struct i2c_master_module *const module)
{
	
}


void configure_i2c_callbacks(void)
{
	/* Register callback function. */
	i2c_master_register_callback(&i2c_master_instance, i2c_write_complete_callback,
	I2C_MASTER_CALLBACK_WRITE_COMPLETE);
	i2c_master_enable_callback(&i2c_master_instance,
	I2C_MASTER_CALLBACK_WRITE_COMPLETE);
}


void printImage(){
	printf("----------START----------");
	for(int loop = 64; loop < 64+64; loop++){
		
		if (loop%8 == 0)
		{
			printf("\r\n");
		}
		
		printf("%d ", i2c_buffer[loop]);
	}
	
	printf("\r\n");
	printf("-------------END--------");
	printf("\r\n");
	
}



static void configure_tcc(uint32_t newVal, uint32_t period)
{
	struct tcc_config config_tcc;
	tcc_get_config_defaults(&config_tcc, CONF_PWM_MODULE);
	config_tcc.counter.period = period;
	config_tcc.compare.wave_generation = TCC_WAVE_GENERATION_SINGLE_SLOPE_PWM;
	config_tcc.compare.match[CONF_PWM_CHANNEL] = newVal;
	config_tcc.pins.enable_wave_out_pin[CONF_PWM_OUTPUT] = true;
	config_tcc.pins.wave_out_pin[CONF_PWM_OUTPUT] =
	CONF_PWM_OUT_PIN;
	config_tcc.pins.wave_out_pin_mux[CONF_PWM_OUTPUT] =
	CONF_PWM_OUT_MUX;
	tcc_init(&tcc_instance, CONF_PWM_MODULE, &config_tcc);
	tcc_enable(&tcc_instance);
}



/**
* \brief ADC START and Read Result.
*
* This function starts the ADC and wait for the ADC
* conversation to be complete	and read the ADC result
* register and return the same to calling function.
*/
/* Structure for ADC module instance */
struct adc_module adc_instance;
uint16_t adc_start_read_result(void)
{
	uint16_t adc_result = 0;
	
	adc_start_conversion(&adc_instance);
	while((adc_get_status(&adc_instance) & ADC_STATUS_RESULT_READY) != 1);
	
	adc_read(&adc_instance, &adc_result);
	
	return adc_result;
}


void process_adc_get(char port, int pin)
{
	int valid_flag = 0;
	
	// need to first set pin as input PIN_PA02, PIN_PA03
	struct port_config config_port_pin;
	port_get_config_defaults(&config_port_pin);
	
	config_port_pin.direction = PORT_PIN_DIR_INPUT;
	config_port_pin.input_pull = PORT_PIN_PULL_UP;
	port_pin_set_config(PIN_PA02, &config_port_pin);
	port_pin_set_config(PIN_PA03, &config_port_pin);
	
	struct adc_config conf_adc;
	
	adc_get_config_defaults(&conf_adc);
	
	conf_adc.clock_source = GCLK_GENERATOR_1;
	conf_adc.clock_prescaler = ADC_CLOCK_PRESCALER_DIV16;
	conf_adc.reference = ADC_REFERENCE_INTVCC1;
	conf_adc.negative_input = ADC_NEGATIVE_INPUT_GND;
	conf_adc.sample_length = ADC_TEMP_SAMPLE_LENGTH;
	conf_adc.positive_input = ADC_POSITIVE_INPUT_PIN0;

	adc_init(&adc_instance, ADC, &conf_adc);
	ADC->AVGCTRL.reg = ADC_AVGCTRL_ADJRES(2) | ADC_AVGCTRL_SAMPLENUM_4;
	adc_enable(&adc_instance);
	raw_result = adc_start_read_result();
	
	float scaled_angle = raw_result/22.75;
	snprintf(servo_msg, 63, "{\"d\":{\"servo\":%d}}", scaled_angle);
	mqtt_publish(&mqtt_inst, SERVO_TOPIC, servo_msg, strlen(servo_msg), 2, 0);
	printf("\r\n%s\r\n",servo_msg);	
	
}



/*HTPP RELATED STATIOC FUNCTIONS*/

/**
* \brief Initialize download state to not ready.
*/
static void init_state(void)
{
	down_state = NOT_READY;
}

/**
* \brief Clear state parameter at download processing state.
* \param[in] mask Check download_state.
*/
static void clear_state(download_state mask)
{
	down_state &= ~mask;
}

/**
* \brief Add state parameter at download processing state.
* \param[in] mask Check download_state.
*/
static void add_state(download_state mask)
{
	down_state |= mask;
}

/**
* \brief File download processing state check.
* \param[in] mask Check download_state.
* \return true if this state is set, false otherwise.
*/

static inline bool is_state_set(download_state mask)
{
	return ((down_state & mask) != 0);
}

/**
* \brief File existing check.
* \param[in] fp The file pointer to check.
* \param[in] file_path_name The file name to check.
* \return true if this file name is exist, false otherwise.
*/
static bool is_exist_file(FIL *fp, const char *file_path_name)
{
	if (fp == NULL || file_path_name == NULL) {
		return false;
	}

	FRESULT ret = f_open(&file_object, (char const *)file_path_name, FA_OPEN_EXISTING);
	f_close(&file_object);
	return (ret == FR_OK);
}

/**
* \brief Make to unique file name.
* \param[in] fp The file pointer to check.
* \param[out] file_path_name The file name change to uniquely and changed name is returned to this buffer.
* \param[in] max_len Maximum file name length.
* \return true if this file name is unique, false otherwise.
*/
static bool rename_to_unique(FIL *fp, char *file_path_name, uint8_t max_len)
{
	#define NUMBRING_MAX (3)
	#define ADDITION_SIZE (NUMBRING_MAX + 1) /* '-' character is added before the number. */
	uint16_t i = 1, name_len = 0, ext_len = 0, count = 0;
	char name[MAIN_MAX_FILE_NAME_LENGTH + 1] = {0};
	char ext[MAIN_MAX_FILE_EXT_LENGTH + 1] = {0};
	char numbering[NUMBRING_MAX + 1] = {0};
	char *p = NULL;
	bool valid_ext = false;

	if (file_path_name == NULL) {
		return false;
	}

	if (!is_exist_file(fp, file_path_name)) {
		return true;
	}
	else if (strlen(file_path_name) > MAIN_MAX_FILE_NAME_LENGTH) {
		return false;
	}

	p = strrchr(file_path_name, '.');
	if (p != NULL) {
		ext_len = strlen(p);
		if (ext_len < MAIN_MAX_FILE_EXT_LENGTH) {
			valid_ext = true;
			strcpy(ext, p);
			if (strlen(file_path_name) - ext_len > MAIN_MAX_FILE_NAME_LENGTH - ADDITION_SIZE) {
				name_len = MAIN_MAX_FILE_NAME_LENGTH - ADDITION_SIZE - ext_len;
				strncpy(name, file_path_name, name_len);
			}
			else {
				name_len = (p - file_path_name);
				strncpy(name, file_path_name, name_len);
			}
		}
		else {
			name_len = MAIN_MAX_FILE_NAME_LENGTH - ADDITION_SIZE;
			strncpy(name, file_path_name, name_len);
		}
	}
	else {
		name_len = MAIN_MAX_FILE_NAME_LENGTH - ADDITION_SIZE;
		strncpy(name, file_path_name, name_len);
	}

	name[name_len++] = '-';

	for (i = 0, count = 1; i < NUMBRING_MAX; i++) {
		count *= 10;
	}
	for (i = 1; i < count; i++) {
		sprintf(numbering, MAIN_ZERO_FMT(NUMBRING_MAX), i);
		strncpy(&name[name_len], numbering, NUMBRING_MAX);
		if (valid_ext) {
			strcpy(&name[name_len + NUMBRING_MAX], ext);
		}

		if (!is_exist_file(fp, name)) {
			memset(file_path_name, 0, max_len);
			strcpy(file_path_name, name);
			return true;
		}
	}
	return false;
}

/**
* \brief Start file download via HTTP connection.
*/
static void start_download(void)
{
	if (!is_state_set(STORAGE_READY)) {
		printf("start_download: MMC storage not ready.\r\n");
		return;
	}

	if (!is_state_set(WIFI_CONNECTED)) {
		printf("start_download: Wi-Fi is not connected.\r\n");
		return;
	}

	if (is_state_set(GET_REQUESTED)) {
		printf("start_download: request is sent already.\r\n");
		return;
	}

	if (is_state_set(DOWNLOADING)) {
		printf("start_download: running download already.\r\n");
		return;
	}
	

	/* Send the HTTP request. */
	printf("start_download: sending HTTP request...\r\n");
	http_client_send_request(&http_client_module_inst, file_url, HTTP_METHOD_GET, NULL, NULL);
}

/**
* \brief Store received packet to file.
* \param[in] data Packet data.
* \param[in] length Packet data length.
*/
static void store_file_packet(char *data, uint32_t length)
{
	FRESULT ret;
	if ((data == NULL) || (length < 1)) {
		printf("store_file_packet: empty data.\r\n");
		return;
	}

	if (!is_state_set(DOWNLOADING)) {
		char *cp = NULL;
		save_file_name[0] = LUN_ID_SD_MMC_0_MEM + '0';
		save_file_name[1] = ':';
		cp = (char *)(file_url + strlen(file_url));
		while (*cp != '/') {
			cp--;
		}
		if (strlen(cp) > 1) {
			cp++;
			strcpy(&save_file_name[2], cp);
			} else {
			printf("store_file_packet: file name is invalid. Download canceled.\r\n");
			add_state(CANCELED);
			return;
		}

		rename_to_unique(&file_object, save_file_name, MAIN_MAX_FILE_NAME_LENGTH);
		printf("store_file_packet: creating file [%s]\r\n", save_file_name);
		ret = f_open(&file_object, (char const *)save_file_name, FA_CREATE_ALWAYS | FA_WRITE);
		if (ret != FR_OK) {
			printf("store_file_packet: file creation error! ret:%d\r\n", ret);
			return;
		}

		received_file_size = 0;
		add_state(DOWNLOADING);
	}

	if (data != NULL) {
		UINT wsize = 0;
		ret = f_write(&file_object, (const void *)data, length, &wsize);
		if (ret != FR_OK) {
			f_close(&file_object);
			add_state(CANCELED);
			printf("store_file_packet: file write error, download canceled.\r\n");
			return;
		}

		received_file_size += wsize;
		printf("store_file_packet: received[%lu], file size[%lu]\r\n", (unsigned long)received_file_size, (unsigned long)http_file_size);
		if (received_file_size >= http_file_size) {
			f_close(&file_object);
			printf("store_file_packet: file downloaded successfully.\r\n");
			port_pin_set_output_level(LED_0_PIN, false);
			add_state(COMPLETED);
			
			return;
		}
	}
}

/**
* \brief Callback of the HTTP client.
*
* \param[in]  module_inst     Module instance of HTTP client module.
* \param[in]  type            Type of event.
* \param[in]  data            Data structure of the event. \refer http_client_data
*/
static void http_client_callback(struct http_client_module *module_inst, int type, union http_client_data *data)
{
	switch (type) {
		case HTTP_CLIENT_CALLBACK_SOCK_CONNECTED:
		printf("http_client_callback: HTTP client socket connected.\r\n");
		break;

		case HTTP_CLIENT_CALLBACK_REQUESTED:
		printf("http_client_callback: request completed.\r\n");
		add_state(GET_REQUESTED);
		break;

		case HTTP_CLIENT_CALLBACK_RECV_RESPONSE:
		printf("http_client_callback: received response %u data size %u\r\n",
		(unsigned int)data->recv_response.response_code,
		(unsigned int)data->recv_response.content_length);
		if ((unsigned int)data->recv_response.response_code == 200) {
			http_file_size = data->recv_response.content_length;
			received_file_size = 0;
		}
		else {
			add_state(CANCELED);
			return;
		}
		if (data->recv_response.content_length <= MAIN_BUFFER_MAX_SIZE) {
			store_file_packet(data->recv_response.content, data->recv_response.content_length);
			add_state(COMPLETED);
		}
		break;

		case HTTP_CLIENT_CALLBACK_RECV_CHUNKED_DATA:
		store_file_packet(data->recv_chunked_data.data, data->recv_chunked_data.length);
		if (data->recv_chunked_data.is_complete) {
			add_state(COMPLETED);
		}

		break;

		case HTTP_CLIENT_CALLBACK_DISCONNECTED:
		printf("http_client_callback: disconnection reason:%d\r\n", data->disconnected.reason);

		/* If disconnect reason is equal to -ECONNRESET(-104),
		* It means the server has closed the connection (timeout).
		* This is normal operation.
		*/
		if (data->disconnected.reason == -EAGAIN) {
			/* Server has not responded. Retry immediately. */
			if (is_state_set(DOWNLOADING)) {
				f_close(&file_object);
				clear_state(DOWNLOADING);
			}

			if (is_state_set(GET_REQUESTED)) {
				clear_state(GET_REQUESTED);
			}

			start_download();
		}

		break;
	}
}

/**
* \brief Callback to get the data from socket.
*
* \param[in] sock socket handler.
* \param[in] u8Msg socket event type. Possible values are:
*  - SOCKET_MSG_BIND
*  - SOCKET_MSG_LISTEN
*  - SOCKET_MSG_ACCEPT
*  - SOCKET_MSG_CONNECT
*  - SOCKET_MSG_RECV
*  - SOCKET_MSG_SEND
*  - SOCKET_MSG_SENDTO
*  - SOCKET_MSG_RECVFROM
* \param[in] pvMsg is a pointer to message structure. Existing types are:
*  - tstrSocketBindMsg
*  - tstrSocketListenMsg
*  - tstrSocketAcceptMsg
*  - tstrSocketConnectMsg
*  - tstrSocketRecvMsg
*/
static void socket_cb(SOCKET sock, uint8_t u8Msg, void *pvMsg)
{
	http_client_socket_event_handler(sock, u8Msg, pvMsg);
}

/**
* \brief Callback for the gethostbyname function (DNS Resolution callback).
* \param[in] pu8DomainName Domain name of the host.
* \param[in] u32ServerIP Server IPv4 address encoded in NW byte order format. If it is Zero, then the DNS resolution failed.
*/
static void resolve_cb(uint8_t *pu8DomainName, uint32_t u32ServerIP)
{
	printf("resolve_cb: %s IP address is %d.%d.%d.%d\r\n\r\n", pu8DomainName,
	(int)IPV4_BYTE(u32ServerIP, 0), (int)IPV4_BYTE(u32ServerIP, 1),
	(int)IPV4_BYTE(u32ServerIP, 2), (int)IPV4_BYTE(u32ServerIP, 3));
	


	http_client_socket_resolve_handler(pu8DomainName, u32ServerIP);
}
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
	int main(void)
	{
		
		
		tstrWifiInitParam param;
		int8_t ret;
		init_state();
		
		/* Initialize the board. */
		system_init();
		configure_nvm();
		
		configure_tcc(0xFFFFF/(2*10.922) * 0.5, 0xFFFFF/1.0921); // starting at 0.5ms width

		delay_init();
		
		/* Initialize the UART console. */
		configure_console();
		printf(STRING_HEADER);
		printf("\r\nThis example requires the AP to have Internet access.\r\n\r\n");

		/* Initialize the Timer. */
// TEMPORARILY COMMENTING THIS OUT> ADD BACK ASAP
// vvvvvvvvvvvvvvvvvvvvvvvvvvvvvvvvvvvvvvvvvvvvvv
// 		configure_timer();

		/* Initialize the HTTP client service. */
		configure_http_client();

		/* Initialize the MQTT service. */
		configure_mqtt();

		/* Initialize the BSP. */
		nm_bsp_init();

		/* Initialize SD/MMC storage. */
// TEMPORARILY COMMENTING THIS OUT> ADD BACK ASAP
// vvvvvvvvvvvvvvvvvvvvvvvvvvvvvvvvvvvvvvvvvvvvvv
//		init_storage();

		/*Initialize BUTTON 0 as an external interrupt*/
		configure_extint_channel();
		configure_extint_callbacks();
		system_interrupt_enable_global();

		/* Initialize Wi-Fi parameters structure. */
		memset((uint8_t *)&param, 0, sizeof(tstrWifiInitParam));

		/* Initialize Wi-Fi driver with data and status callbacks. */
		param.pfAppWifiCb = wifi_cb;
		ret = m2m_wifi_init(&param);
		if (M2M_SUCCESS != ret) {
			printf("main: m2m_wifi_init call error! (res %d)\r\n", ret);
			while (1) {
			}
		}

// TEMPORARILY COMMENTING THIS OUT> ADD BACK ASAP
// vvvvvvvvvvvvvvvvvvvvvvvvvvvvvvvvvvvvvvvvvvvvvv
		if (SysTick_Config(system_cpu_clock_get_hz() / 1000))
		{
			puts("ERR>> Systick configuration error\r\n");
			while (1);
		}
		
		socketInit();
		registerSocketCallback(socket_event_handler, socket_resolve_handler);
		
		/* Connect to router. */
		printf("main: connecting to WiFi AP %s...\r\n", (char *)MAIN_WLAN_SSID);
		m2m_wifi_connect((char *)MAIN_WLAN_SSID, sizeof(MAIN_WLAN_SSID), MAIN_WLAN_AUTH, (char *)MAIN_WLAN_PSK, M2M_WIFI_CH_ALL);
		
		printf("main: please unplug the SD/MMC card.\r\n");
		printf("main: done.\r\n");

		delay_s(1);
		
		deconfigure_console();
		InitializeSerialConsole();
		
		
		packet.address = SLAVE_ADDRESS;
		packet.data_length = DATA_LENGTH;
		packet.data = i2c_buffer;
		
		/* Configure device and enable. */
		configure_i2c();
		/* Configure callbacks and enable. */
		configure_i2c_callbacks();
		
// TEMPORARILY COMMENTING THIS OUT> ADD BACK ASAP
// vvvvvvvvvvvvvvvvvvvvvvvvvvvvvvvvvvvvvvvvvvvvvv
//		currentStatus = readFWVersion();

		volatile int count = 0;
				
		delay_ms(300);
		
		while (1) {		
			
			/* Handle pending events from network controller. */
			m2m_wifi_handle_events(NULL);
			
			if(isPressed)
			{
				//Publish updated temperature data
				mqtt_publish(&mqtt_inst, TEMPERATURE_TOPIC, mqtt_msg, strlen(mqtt_msg), 2, 0);
				isPressed = false;
				delay_ms(200);
			}

			if (enterSeen == 1)
			{
				enterSeen = 0;
				matchCommand();
			}

			//Handle MQTT messages
			if(mqtt_inst.isConnected) mqtt_yield(&mqtt_inst, 100);
			
			
			if(updateReady){
				
				printf("Detected update \r\n");
				
				f_unlink("ApplicationCode.bin");
				
				/* Force close the MQTT connection, because cannot
				send a disconnect message to the broker when network is broken. */
				mqtt_disconnect(&mqtt_inst, 1);

				delay_s(1);
				
				do_download_flag = true;
				
				/* Initialize socket module. */
				registerSocketCallback(socket_cb, resolve_cb);
				
				start_download();

				while (!(is_state_set(COMPLETED) || is_state_set(CANCELED))) {
					/* Handle pending events from network controller. */
					m2m_wifi_handle_events(NULL);
					/* Checks the timer timeout. */
					sw_timer_task(&swt_module_inst);
				}
				
				if(!is_state_set(DOWNLOADING) && is_state_set(GET_REQUESTED) && is_state_set(WIFI_CONNECTED)){
					
				}
				
				do_download_flag = false;

				registerSocketCallback(socket_event_handler, socket_resolve_handler);
				
				/* Connect to router. */
				if (mqtt_connect(&mqtt_inst, main_mqtt_broker)){
					printf("Error connecting to MQTT Broker!\r\n");
				}
				printf("Finished update  \r\n");
				updateReady = !updateReady;
				delay_s(1);
				printf("Finished update \r\n");
				
				NVIC_SystemReset();
			}
			

		}

		return 0;
	}

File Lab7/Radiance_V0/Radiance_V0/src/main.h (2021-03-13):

/**
 * \file
 *
 * \brief HTTP File Downloader Example.
 *
 * Copyright (c) 2016-2018 Microchip Technology Inc. and its subsidiaries.
 *
 * \asf_license_start
 *
 * \page License
 *
 * Subject to your compliance with these terms, you may use Microchip
 * software and any derivatives exclusively with Microchip products.
 * It is your responsibility to comply with third party license terms applicable
 * to your use of third party software (including open source software) that
 * may accompany Microchip software.
 *
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
 * \asf_license_stop
 *
 */

#ifndef MAIN_H_INCLUDED
#define MAIN_H_INCLUDED

#ifdef __cplusplus
extern "C" {
#endif
#include "SerialConsole/SerialConsole.h"
/** Wi-Fi AP Settings. */
//#define MAIN_WLAN_SSID                       "OnePlus" /**< Destination SSID */
#define MAIN_WLAN_SSID                       "AirPennNet-Device" /**< Destination SSID */
#define MAIN_WLAN_AUTH                       M2M_WIFI_SEC_WPA_PSK /**< Security manner */
//#define MAIN_WLAN_AUTH                       M2M_WIFI_SEC_OPEN/**< Security manner */
#define MAIN_WLAN_PSK                        "penn1740wifi" /**< Password for Destination SSID */

//#define MAIN_WLAN_PSK                        "Radiance" /**< Password for Destination SSID */
/** IP address parsing. */
#define IPV4_BYTE(val, index)                ((val >> (index * 8)) & 0xFF)

/** Content URI for download. */
//#define MAIN_HTTP_FILE_URL                   "http://www.orimi.com/pdf-test.pdf"

#define APP_FILE_URL                   "https://www.seas.upenn.edu/~sheils/ApplicationCode.bin"
#define META_FILE_URL                   "https://www.seas.upenn.edu/~sheils/metadata.txt"


/** Maximum size for packet buffer. */
#define MAIN_BUFFER_MAX_SIZE                 (1446)
/** Maximum file name length. */
#define MAIN_MAX_FILE_NAME_LENGTH            (250)
/** Maximum file extension length. */
#define MAIN_MAX_FILE_EXT_LENGTH             (8)
/** Output format with '0'. */
#define MAIN_ZERO_FMT(SZ)                    (SZ == 4) ? "%04d" : (SZ == 3) ? "%03d" : (SZ == 2) ? "%02d" : "%d"



typedef enum {
	NOT_READY = 0, /*!< Not ready. */
	STORAGE_READY = 0x01, /*!< Storage is ready. */
	WIFI_CONNECTED = 0x02, /*!< Wi-Fi is connected. */
	GET_REQUESTED = 0x04, /*!< GET request is sent. */
	DOWNLOADING = 0x08, /*!< Running to download. */
	COMPLETED = 0x10, /*!< Download completed. */
	CANCELED = 0x20 /*!< Download canceled. */
} download_state;


/* Max size of UART buffer. */
#define MAIN_CHAT_BUFFER_SIZE 256

/* Max size of MQTT buffer. */
#define MAIN_MQTT_BUFFER_SIZE 512

/* Limitation of user name. */
#define MAIN_CHAT_USER_NAME_SIZE 64

/* MCU is Publisher */
#define TEMPERATURE_TOPIC	"TempData"
#define LOCATION_TOPIC		"LocationData"
#define BATTERY_TOPIC		"BatteryData"
#define IMAGE_TOPIC			"ImageData"
#define SERVO_TOPIC			"ServoData"

// MCU is Subscriber
#define STOP_TOPIC			"StopData"
#define LED_TOPIC			"LedData"
#define ANGLE_TOPIC			"RotationData"
#define FW_TOPIC			"FWData"
#define CRC_TOPIC			"CRCData"
#define VER_TOPIC			"VerData"
#define LED_TOPIC_LED_OFF	 "false"
#define LED_TOPIC_LED_ON	 "true"

//Cloud MQTT User
#define CLOUDMQTT_USER_ID	"svxscavo"


//Cloud MQTT pASSWORD
#define CLOUDMQTT_USER_PASSWORD	"x-4tm-tmbE5V"

#define CLOUDMQTT_PORT		19654

/*
 * A MQTT broker server which was connected.
 * m2m.eclipse.org is public MQTT broker.
 */
static const char main_mqtt_broker[] = "m16.cloudmqtt.com";

#define ver_bl "\r\n1.1.2 \r\n"
#define MAX_RX_BUFFER_LENGTH   10
volatile uint8_t rx_buffer[MAX_RX_BUFFER_LENGTH];

char file_url[256]  = APP_FILE_URL;


typedef struct Status{
	char fw_version[32];
	char crc32[32];
	uint8_t flag;
} Status;
#ifdef __cplusplus
}
#endif

#endif /* MAIN_H_INCLUDED */

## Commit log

2021-03-12 added imgs and refs
    [Altium_ESE516_BOM.xlsx, TM2ESE516_SAMW25_PinAssignments_vF.xlsx]
2021-03-12 added lab0
    [BOM_A0.xlsx]
2021-03-12 Lab 2
    [ESE516_SAMW25_PinAssignments_V1.xlsx, Nikhil Jamdade_A0_BOM.xlsx]
2021-03-13 Lab 4
    [Altium_ESE516_Lab4_BOM.xlsx]
2021-03-13 took pdf printouts
    [10118192-0001LF.PcbLib, 3.3VBuck.SchDoc, 3.3V_buck.SchLib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]
2021-03-13 added schematics
